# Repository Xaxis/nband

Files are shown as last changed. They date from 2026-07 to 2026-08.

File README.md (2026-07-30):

# nband

An open multi-spectral sensing platform. A buildable sensor node that watches the sky across as many as thirteen bands at once, timestamps everything against a satellite-disciplined clock, and publishes what it records.

**Site:** https://nband.space

The motivating question is whether anything crosses the sky that conventional explanations do not cover. The design commitment is that the instrument is never allowed to claim more than it measured. The top of the classification ladder is `unresolved`, not `artificial`, and the schema has no way to encode the latter.

## What is in here

Hardware, firmware, database, analysis, and documentation are one repository on one version, because documentation that drifts from the hardware is worse than no documentation. `make check` fails when they diverge.

```
schema/         Canonical source of truth. bands.json and spec.json define the band
                taxonomy, enums, hypothesis set, and platform thresholds. Everything
                else is generated from them.
firmware/       The node agent. Python, runs on a Raspberry Pi 5, runs anywhere in
                --simulate mode.
discriminator/  The analysis engine. Subtracts known sources, scores hypotheses,
                produces verdicts that explain themselves.
apps/web/       The site: landing, documentation, hardware registry, live telemetry,
                and the grid ingest API.
content/        Flat-file documentation, versioned beside the firmware it describes.
tools/          codegen, the four checks, seeding, fixtures, palette derivation.
```

## The parts that are load-bearing

**One schema, three languages.** `tools/codegen.mjs` generates TypeScript for the website and Python for the firmware from `schema/*.json`. The Postgres enums are checked against the same files. Adding a band means editing one file; there is no second place to forget.

**Timing is the whole product.** A node disciplines its clock against GNSS with a hardware pulse-per-second signal and holds a few hundred nanoseconds. That is what makes cross-band coincidence a measurement rather than a figure of speech, and what lets two nodes triangulate a real altitude. A node without PPS keeps recording and marks its data as unable to contribute geometry.

**Nanoseconds travel as strings.** Nanoseconds since the epoch is roughly 1.8×10¹⁸, two orders of magnitude past `Number.MAX_SAFE_INTEGER`. Sent as a JSON number it arrives already rounded, destroying exactly the precision the PPS lock exists to buy. Nodes send decimal strings; the API parses them as `BigInt`.

**Unavailable is not the same as clean.** Every catalogue lookup is recorded in three states: matched, checked and clean, or unreachable. An event with any unreachable catalogue cannot be called unresolved. Conflating those two is the easiest way to manufacture a mystery, and the test suite exists mostly to prevent it.

**Colour never carries meaning alone.** Fourteen bands cannot be separated by hue under colour-vision deficiency at any spacing; this was measured with a palette validator, not assumed. So band colour is an accent beside a written label, and the telemetry view uses one chart per band rather than fourteen overlaid traces.

**Requests are single-use.** Every write is Ed25519-signed over the path, a timestamp, and a nonce as well as the body. The grid records each nonce, so a captured request cannot be replayed to fabricate archive content.

## Running it

Everything goes through `make`. `make` on its own lists the targets.

```bash
make install        # JS and Python dependencies
make dev            # site at localhost:3000, against the mock feed
make check          # everything CI runs
make node-selftest  # open every channel in simulation, no hardware needed
```

`make check` runs seven things, each of which is a claim this repository makes
about itself:

| Target | What it proves |
|---|---|
| `make drift` | Generated bindings, Postgres enums, document versions, part cross-references, tier budgets, power sizing, band counts and the documented wire protocol all agree |
| `make parity` | The browser discriminator scores identically to the Python engine |
| `make links` | Every internal link resolves and every document has a route |
| `make privacy` | A published node position cannot be de-fuzzed back to an operator's home |
| `make test-firmware` | Clock grading, bounded buffers, coincidence triggering, driver registry |
| `make test-discriminator` | The scoring engine, mostly asserting what it refuses to conclude |
| `make lint` `make build` | Types, lints, and a production build |

## Build one

Three tiers, priced from named vendor pages on a stated date. Component pricing moved sharply through 2026 as memory supply was redirected to AI datacentre demand, so the entry tier targets a 2 GB board and the firmware is written to fit it rather than pretending prices held.

See [/hardware](https://nband.space/hardware) for the bill of materials and [/build](https://nband.space/build) for the guide. Every build step ends in something you can verify before spending money on the next one.

If you are within 60 km of an existing node, put yours there. A second node with a good clock converts both from bearing-only instruments into a system that measures position, and that is worth more than any single sensor upgrade.

## Documentation

Everything is published at [nband.space](https://nband.space) and lives in
`content/` beside the firmware it describes. Start at
[nband.space/docs](https://nband.space/docs), or go straight to one of these:

- [What the fourteen bands can and cannot see](https://nband.space/bands)
- [Bill of materials, wiring, and power budget](https://nband.space/hardware)
- [Build guide](https://nband.space/build), eleven steps, each one verifiable
- [How verdicts are reached](https://nband.space/discriminator), runs live
- [Safety and regulation](https://nband.space/safety), read before building an emitter

## Contributing

See [CONTRIBUTING.md](CONTRIBUTING.md), and
[SECURITY.md](SECURITY.md) for the threat model and how to report a
vulnerability. Changes of note are recorded in [CHANGELOG.md](CHANGELOG.md).

## Licence

Code MIT. Documentation and recorded data CC BY 4.0. See [LICENSE](LICENSE).

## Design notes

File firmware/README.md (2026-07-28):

# nband node agent

The software that runs on the node. Samples every configured band, decides what is worth keeping, and delivers it to the grid without losing anything when the link goes down.

Runs on a Raspberry Pi 5. Runs on a laptop in `--simulate` mode, which is how the build guide lets you verify the whole pipeline before any hardware arrives.

```bash
python3 -m venv .venv && .venv/bin/pip install -e '.[pi]'
python3 -m nband_node.agent --config config.example.toml --simulate --self-test
```

## The memory budget

Tier 1 targets a 2 GB Raspberry Pi 5 because the 8 GB board costs USD 110 more at July 2026 prices, and that difference is a quarter of the entire tier 1 budget. Fitting in 2 GB is not an optimisation applied afterwards; it is a constraint the architecture is built around.

Three rules make it hold.

**Every buffer is bounded at construction.** `RingBuffer` takes a capacity and never resizes. Ring depth is `sample_rate_hz × (pre_roll_s + post_roll_s)`, capped at 20,000 samples per channel. A tier 2 node with eight channels holds well under 50 MB of sample history, and that figure is the same after a month of uptime as after a minute.

**Nothing decoded is queued.** Imaging drivers return a photometric scalar per frame, not the frame. A full 12-megapixel capture is roughly 36 MB decoded; queuing even a few would exhaust the board. Frames are held only inside the driver for the duration of one read, and full captures reach durable storage only when a detection promotes the window that contains them.

**The noise floor is constant-memory.** `NoiseFloor` uses Welford's algorithm rather than a window of recent samples, so a channel's adaptive threshold costs three floats regardless of how long the node has been running. A windowed implementation at 10 Hz over an hour would be 36,000 samples per channel for no additional accuracy.

The practical consequence for driver authors: if your `read()` allocates something proportional to uptime, or holds a decoded frame past return, it will work on your desk and strand a node in the field three weeks later.

## What the agent does each cycle

Reads any channel whose next sample is due. Appends the sample to that channel's ring buffer and to the local spool. Updates the channel's noise floor, but only with clean samples, because feeding a saturated reading into the floor teaches the channel that saturation is normal.

If a sample exceeds its channel's `trigger_sigma`, it is offered to the coincidence detector. A single crossing is held, not published. It becomes a detection when a second *band* crosses inside the coincidence window, or when one channel's excursion is extreme enough to be worth recording alone at a much lower score. Two cameras both seeing a bird is one observation, not corroboration, which is why the detector counts distinct bands rather than distinct channels.

When a detection fires, the window is promoted: every channel's buffered samples from `pre_roll_s` before the trigger to `post_roll_s` after it are written to the detection spool. That pre-roll is the reason the ring buffer exists at all.

## Offline-first

A node on a desert mast with intermittent backhaul is the design case, not the edge case.

Samples go to an append-only local spool first and are removed only once the grid acknowledges them. When the spool reaches its ceiling it drops the oldest *telemetry* and never touches detections: losing an hour of barometric pressure costs almost nothing, and losing a detection costs the entire point of the exercise.

A node with no network at all is a valid deployment. It accumulates until the disk fills and uploads in order when a link appears.

## Timing

The agent does not discipline the clock. `chrony` does that, against the GNSS pulse-per-second signal. What the agent does is read back how well disciplined the clock currently is and record that honestly with every sample.

`Clock.update_from_chrony` grades conservatively: the reference must actually be a PPS source and the RMS offset must be under a microsecond before the node claims `gnss_pps`. Anything else is `ntp` or `freerun`, and every sample taken under those conditions carries the clock-degraded quality bit.

This matters because cross-node time-of-arrival is the only way the grid measures position rather than bearing, and a node that overstates its timing corrupts geometry for every node it is correlated against.

## Layout

```
nband_node/
  config.py            TOML loading and hard validation
  core.py              Clock, RingBuffer, NoiseFloor, CoincidenceDetector
  sensors.py           Driver interface, simulated twins, 17 real drivers
  agent.py             Main loop, identity, spool, grid client, CLI
  schema_generated.py  Generated from schema/. Never edit.
tests/
  test_core.py         Clock grading, buffers, triggering
  test_registry.py     Every advertised driver exists and resolves
```

## Adding a driver

Subclass `Driver`, declare a band, implement `read()`. Four things are easy to get wrong and all of them are silent:

Declare capabilities honestly. `Capabilities` is how the discriminator knows whether it may score thermal morphology or only thermal presence. Overstating it corrupts analysis rather than improving it.

Return `None` rather than a fabricated value when a read fails. Several of these sensors drop frames routinely and the pipeline handles it. A zero standing in for a missing reading poisons the noise floor.

Mark compromised samples with the quality bitfield instead of dropping them. A silent gap reads as "nothing happened" when it means "we could not trust this".

Write the simulated path. `test_registry.py` requires every band to produce a sample under `--simulate`, so that someone without your hardware can still exercise the pipeline.

## Tests

```bash
python3 tests/test_core.py       # 16 cases
python3 tests/test_registry.py   #  6 cases
```

`test_registry.py` exists because thirteen drivers were once advertised in the hardware registry and the shipped example config with no implementation behind them. That config is what the build guide tells people to run, so it would have failed at the exact moment a builder had just soldered something and had every reason to blame their own wiring.

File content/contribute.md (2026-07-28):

---
title: Contributing
description: How to add hardware variants, drivers, catalogues, and documentation without breaking the archive for everyone else.
version: 0.1.0
section: Participate
order: 70
updated: 2026-07-27
audience: Anyone who wants to extend the platform
---

nband is built on the assumption that people will construct it with parts nobody anticipated. The registry, the driver interface, and the capability declaration all exist to make that a supported path rather than a fork.

## The one rule that matters

Do not add anything that makes the archive claim more than the instrument measured.

Almost every design decision in this project follows from that. It is why the discriminator records a catalogue it could not reach separately from a catalogue that found nothing, why range stays null unless something measured it, why a driver declares what it cannot resolve, and why the top of the classification ladder is "unresolved" rather than anything more interesting. A contribution that quietly widens what the data appears to support will be refused even if the code is good.

## Registering a hardware variant

If you built a node with a substitute part, register it. An unregistered part means the grid receives data it cannot calibrate and has to discount.

A variant entry needs the band it serves, the driver it uses, a sourced price with a date, and an honest account of what it cannot do. The MLX90640 entry is the model to follow: it is a fully supported thermal variant at a fifth of the reference price, and its registry entry states plainly that at 768 pixels it can establish thermal presence but not thermal morphology. The discriminator reads that and scores accordingly.

New variants enter as `submitted`. Data from a submitted part is accepted and flagged. Running the conformance suite and having it pass moves the part to `verified`, at which point the flag comes off. Parts that do not work are documented as `unsupported` rather than deleted, so nobody buys one twice.

## Writing a driver

Subclass `Driver`, declare a band, implement `read()`, and return a `Sample`. The parts that are easy to get wrong:

Declare your capabilities honestly. `Capabilities` is how the discriminator knows whether it may score thermal morphology or only thermal presence. Overstating it corrupts analysis rather than improving it.

Return `None` rather than a fabricated value when a read fails. A dropped frame is normal for several of these sensors and the pipeline handles it. A zero standing in for a missing reading is a lie that propagates into the noise floor.

Mark compromised samples instead of dropping them. The quality bitfield exists so that a saturated sensor, a stale calibration, or a shutter event stays visible in the record. A silent gap reads as "nothing happened" when it means "we could not trust this".

Write a simulated path. Every driver needs to work under `--simulate` so that someone without your hardware can still exercise the pipeline, and so the build guide's verification steps work before parts arrive.

## Adding a catalogue

Catalogues subtract known sources. A new one implements `check()` and returns a `CatalogResult`.

The critical contract is that unreachable is not the same as clean. If your provider times out, raises, or returns nothing, return `available=False`. Returning a no-match result for a failed lookup is the single most damaging bug possible in this codebase: it manufactures mysteries by making unchecked events look checked. The test suite has cases for exactly this and they are not optional.

## Changing the schema

`schema/bands.json` and `schema/spec.json` are the source of truth for the whole platform. Editing them and running `yarn codegen` regenerates the TypeScript and Python bindings; `yarn check:drift` fails if you forgot.

Band `ordinal` values are persisted in the database. Reordering bands is a breaking change and needs a schema version bump and a migration, not an edit.

## Documentation

Content lives in `/content` at the repository root, next to the firmware rather than inside the website. Each document declares the platform version it was written against, and the drift check fails the build when a document claims a version that no longer exists.

If you change firmware behaviour that a document describes, change the document in the same commit. Documentation that drifts from the hardware is worse than no documentation, because it is trusted.

## Running the tests

Everything goes through `make`, and `make check` is exactly what CI runs. Run that before opening a pull request and there should be no surprises:

```bash
make install     # JS and Python dependencies, pinned to match CI
make check       # everything CI runs
```

If you want the fast loop while working, `make check-fast` skips the production build. Each target is a claim the repository makes about itself:

| Target | What it proves |
|---|---|
| `make drift` | Generated bindings, Postgres enums, document versions, part cross-references, tier budgets, power sizing, band counts and the documented wire protocol all agree |
| `make parity` | The browser discriminator scores identically to the Python engine |
| `make links` | Every internal link resolves and every document has a route |
| `make privacy` | Published node positions cannot be de-fuzzed back to an operator's home |
| `make test` | Clock grading, bounded buffers, coincidence triggering, driver registry, and the scoring engine |
| `make lint` `make build` | Types, lints, and a production build |

The discriminator tests are mostly about refusal: they assert that events get downgraded when the clock is degraded, when a catalogue was unavailable, or when only one band saw it. Those are the cases that protect the archive from false claims, which is the only failure mode that actually costs this project anything.

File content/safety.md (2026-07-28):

---
title: Safety and regulation
description: Optical, radio, electrical, and radiological hazards in an nband build, and the rules that apply to each.
version: 0.1.0
section: Reference
order: 60
updated: 2026-07-27
audience: Anyone building the active-emission module, and everyone else before they power up outdoors
---

Most of a nband node is passive and carries no more risk than a garden camera. The exceptions are concentrated in the optional active-emission module and in the fact that the whole thing lives outdoors on a mast.

Nothing here is legal advice. Rules differ by country and the operator is responsible for the ones that apply where the node stands.

## The passive build is genuinely low risk

Tier 1 emits nothing at all. Tier 2 is not passive: its bill of materials includes a 24 GHz tracking radar, which is an intentional radiator, and the optional 850 nm beacon if you fit one. Everything else in both tiers only receives. The hazards are otherwise the ordinary ones of outdoor electronics: a lithium battery that should not be punctured or charged below freezing, a mast that should not be raised near overhead lines, and mains wiring that should be on a residual-current device if it exists at all.

The one non-obvious risk is the lens. A large-aperture lens pointed at the sky will, at some point, be pointed near the Sun. This will not hurt you but it can destroy a sensor in seconds and can ignite debris inside an enclosure. If your node tracks, add a solar-exclusion zone to its pointing limits. If it stares, accept that a fixed camera looking upward will image the Sun daily and choose an aperture accordingly.

## Ultraviolet and infrared sensors are receivers, not emitters

The UV and thermal channels detect radiation, they do not produce it. There is no exposure risk from the sensors themselves. The germanium window in front of a thermal camera is brittle and moderately expensive and is the part most likely to be damaged by cleaning it with the wrong cloth.

## The infrared beacon is the one optical emitter

The 850 nm pulsed beacon is an LED rather than a laser. That matters for which standard applies, not for whether it is safe: LEDs are assessed under IEC 62471 photobiological safety rather than the IEC 60825 laser classes, and a 5 W peak infrared emitter is not automatically in the exempt group at close range. Earlier wording here implied the LED construction alone put it below a Class 3R threshold, which conflates two different standards.

Treat it as a real emitter. 850 nm is barely visible, so the blink reflex does not protect you. Do not look into it at close range, do not view it through binoculars or a camera with gain, keep it above head height, and do not point it at a road, a footpath, or anything on approach to an airfield.

Point it above the horizon. The node knows its own emission schedule exactly, so any near-infrared return correlating with the code is recognised as self-illumination and subtracted rather than reported.

## The broadband RF source is not something you can build under Part 15

An earlier revision of this page said the optional noise source ran "under 100 mW effective radiated power, inside FCC Part 15". That was wrong in a way worth stating plainly, because someone might have built it.

There is no general 100 mW allowance in Part 15. The 1 W figure people remember applies to digitally modulated or frequency-hopping systems inside the ISM bands under §15.247, and 400 to 600 MHz is not an ISM band. An intentional radiator there falls under the general radiated-emission limits of §15.209, which are expressed as field strength at three metres and correspond to something on the order of nanowatts, not milliwatts. Spreading the signal does not help: §15.209 constrains field strength, not power spectral density.

So that emitter has been withdrawn from the reference design. Building a deliberate broadband radiator in that range at any useful power requires an amateur or experimental licence, and if you hold one you already know more about the conditions attached to it than this page can usefully tell you.

The millimetre-wave radar modules are a different case. They are certified devices sold for exactly this use and operating in bands allocated for it. Leave their firmware alone; the certification belongs to the module as shipped, not to whatever you reflash it with.

## The radioisotope module needs to be read carefully

The optional signature module aggregates the encapsulated americium-241 foils already present in domestic ionisation smoke detectors. Roughly ten of them, at about 0.9 microcuries each, sit behind a 2 mm aluminium heat sink and an acrylic housing. The aluminium and acrylic absorb the alpha and beta emission entirely while remaining largely transparent to the 59.5 keV gamma line, which is the signature the module exists to produce.

This page published the dose figure wrong twice, in opposite directions. Both are corrected here rather than quietly replaced, because both were live long enough to be read.

The figure first published was roughly 40 nanogray per hour at one metre, described as "well under one percent of natural background". A later revision retracted it and claimed about 1,070 nanosieverts per hour, three times background. **The retraction was itself wrong**, by about a factor of a hundred, and it is the number that stood.

The error was a dropped exponent. The tabulated air-kerma rate constant for americium-241 is roughly 3.2 × 10⁻² mGy·m²/(GBq·h). Converting milligray to microgray multiplies by a thousand and converting gigabecquerels to megabecquerels divides by a thousand, so those cancel and the value in the units wanted is still 3.2 × 10⁻², or 0.032 µSv·m²/(MBq·h). It was published as 3.2.

Worked through properly: nine microcuries is 0.33 megabecquerels. The 59.5 keV line alone, at 35.9 percent yield against NIST mass energy-absorption coefficients for air, gives about **1 nSv/h at one metre**. Including the neptunium L X-rays around 14 to 21 keV, which are soft but numerous, raises it to about **9 nSv/h**. The most conservative published constant found in a supplier safety sheet, 85 µSv/h per GBq, gives **28 nSv/h**. Natural background averages around 340 nSv/h.

Across the full spread of defensible values the answer is between a fraction of a percent and about eight percent of background. It is never above background. The figure this page published as three times background was wrong in the alarming direction by roughly two orders of magnitude, and the original 40 nGy/h was about right in magnitude, though its label was not: 40 nGy/h is around twelve percent of background, not "well under one percent".

Shielding was also described wrongly. Two millimetres of aluminium passes about 86 percent of the 59.5 keV line, which is where the claim that it "does not rescue it" came from, but only about 16 percent of the 17 keV L X-rays, and those dominate the bare dose. The housing removes most of it. That was never the reason to shield: alpha and beta are what the aluminium and acrylic stop, and they do that completely.

**The dose was never the problem.** A few percent of background at one metre, falling off as the square of distance, is not what should stop you. The regulatory position is.

The regulatory position was published wrongly too, and it matters more than the dose figure. An earlier revision said the assembly "stays below the United States NRC general-license threshold in 10 CFR 30.15". That is not what 10 CFR 30.15 says. It is an exemption rather than a general license, general licenses live in Part 31, and §30.15(a)(7) exempts "ionization chamber smoke detectors containing not more than 1 microcurie of americium-241 per detector in the form of a foil and designed to protect life and property from fires". The limit is per detector, the exemption attaches to the detector as a fire-protection device, and there is no aggregate activity allowance to sit beneath.

Ten foils removed from their detectors and epoxied into an aluminium and acrylic cartridge is therefore outside that exemption on every count: nine times the per-item activity, no longer in a device designed to protect life and property from fires, and no longer the article the exemption describes. §30.15(b) points anyone wanting to incorporate byproduct material into a product towards a specific license under §32.14.

nband does not assert that building this is lawful, and the previous wording implied a regulatory cover that does not exist. The aggregated cartridge has been removed from the reference bill of materials. If you intend to pursue a gamma lure seriously, do it under a specific license with your regulator's knowledge, not on the strength of a citation you read on a website.

The handling advice stands regardless: do not open, machine, dissolve, or heat a foil. It is dangerous if the encapsulation is breached and ingested, and unremarkable if left alone.

Outside the United States, rules differ substantially and some jurisdictions prohibit possession of multiple sources regardless of individual activity. Check before building, not after.

If any of this is uncomfortable, skip the module. It is genuinely optional, every passive band works without it, and the platform is designed so that an emitter-free node is a first-class participant rather than a degraded one.

## Cameras and other people

A node pointed at the sky is not a surveillance device, but a wide-angle lens on a mast usually catches some ground. In populated areas, tilt the field of view at least 15 degrees above the horizon and confirm what is actually in frame rather than assuming.

Published node positions are fuzzed to the precision the operator declares, defaulting to one kilometre. The offset is deterministic, so repeated readings cannot be averaged back to the true point, and it is keyed on a server-held secret, so it cannot simply be recomputed and subtracted. Both properties are required; in 0.1.0 this platform had only the first, and the published position was recoverable to a few metres by anyone who read the source. That protects the operator. It does nothing for the neighbours, which is the operator's job.

## Aviation

A ground node on a mast is not an aviation matter until the mast is tall. Structures above roughly 60 metres, and anything near an aerodrome approach, are subject to marking and notification requirements almost everywhere.

If you are mounting the payload on an aircraft of any kind, everything about that is outside the scope of this guide and squarely inside your national aviation regulator's.

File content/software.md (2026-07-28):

---
title: Software and configuration
description: Flashing, configuration, calibration, the data schema, and the API surface a node speaks to the grid.
version: 0.1.0
section: Build
order: 20
updated: 2026-07-27
audience: Someone with a node running who wants to change how it behaves
---

The node agent is a single Python package with no service dependencies beyond the grid endpoint. It is designed to run for months without attention on a board with 2 GB of memory, which constrains the architecture more than anything else: every buffer is bounded at construction, nothing in the hot path grows with uptime, and decoded frames are never queued.

## The configuration file is the whole interface

A node is defined entirely by one TOML file. There is no hidden state and no auto-detection, deliberately. A node that silently reconfigures itself produces an archive nobody can interpret two years later, because the metadata explaining a reading is no longer recoverable from the reading.

The file is validated hard at startup and the agent refuses to run if anything is ambiguous. That includes rejecting a `trigger_sigma` on a context band, which is how the platform structurally prevents a barometric wobble from being reported as a detection.

```toml
[node]
name = "KP-01 Sonoran"
tier = "t2"
pre_roll_s = 15.0     # buffered history promoted when a trigger fires
post_roll_s = 15.0

[site]
latitude = 31.9403
longitude = -109.3120
elevation_m = 1402.0
location_precision_m = 1000   # published position is fuzzed by this radius

[grid]
endpoint = "https://nband.space"
node_slug = "kp-01-sonoran"
key_path = "/var/lib/nband/node.key"

[[channel]]
id = "vis.wide"
band = "vis"
part = "cam-hq-imx477"
unit = "mag/arcsec2"
sample_rate_hz = 0.2
trigger_sigma = 4.5
```

`part` refers to an entry in the hardware registry and resolves automatically to a driver. Specify `driver` directly only when using hardware the registry does not know about, and register the variant afterwards so the next person does not have to guess.

## Choosing trigger thresholds

`trigger_sigma` is measured in standard deviations of that channel's own running noise floor, not in absolute units. This is what lets the same configuration work at a rural site and a suburban one whose radio floor is thirty decibels higher.

The floor is computed with Welford's algorithm over the channel's whole history, so it adapts slowly and does not need recomputing from a window. It requires 64 samples before it will fire at all, which on a 0.2 Hz channel is five minutes. A node that has just restarted is deliberately deaf for that period rather than firing on its own startup transient.

Start at `4.5` for imaging channels and `6.0` for radio. Lower values produce more candidate events, which is not the same as producing more information: the coincidence requirement means a channel that fires constantly mostly generates noise for the other channels to fail to corroborate. If a channel is triggering more than a few times an hour, raise its sigma rather than filtering downstream.

## Calibration

Three channels need calibration before their data means anything in absolute terms.

The magnetometer needs a hard-iron offset, measured by rotating the sensor through all orientations and recording the midpoint of each axis. Without it the channel still detects changes correctly but reports the wrong absolute field, which matters when comparing across nodes.

The thermal camera's flat-field shutter runs automatically every few minutes and blanks the stream for roughly half a second. The agent marks those samples with the calibration-stale quality bit rather than dropping them, so a gap in the record is always visible as a gap rather than as an absence of events.

The sky-brightness channel needs a zero point, which is the reading on a clear moonless night with no artificial light in frame. Until you set it, the channel reports relative values and the discriminator scores it accordingly.

## The data schema

Everything the platform records derives from two files in the repository, `schema/bands.json` and `schema/spec.json`. Those define the band taxonomy, the enumerations, the hypothesis set, and the platform-wide thresholds. TypeScript for the website and Python for the firmware are generated from them by `yarn codegen`, and a drift check fails the build if the generated files are stale.

This is why the website and the node cannot disagree about what a band is. Adding a band means editing one JSON file and regenerating; there is no second place to update and forget.

Two details in the storage schema are worth knowing. Timestamps are stored as a Postgres `timestamptz`, which holds microseconds, plus a separate `t_ns_offset` column holding the remaining 0 to 999 nanoseconds. Nanosecond fidelity therefore survives the round trip, which matters only for cross-node time-of-arrival work but matters completely there. And verdicts are versioned per discriminator run rather than overwritten, so re-running an improved discriminator over the archive produces a new verdict alongside the old one instead of quietly rewriting history.

## The API surface

Four endpoints, all requiring an Ed25519 signature using the node's key. The signature covers a canonical payload, `nband/v1\n{path}\n{timestamp}\n{nonce}\n{body}`, rather than the body alone, so a captured request cannot be replayed onto a different endpoint or reused at all. See [the API reference](/reference/api) for the exact header set.

`POST /api/grid/register` enrols a node and declares its channels. Re-enrolment by a node signing with the key already on record is allowed and is how you update the channel list after adding hardware. Enrolling a new slug requires the grid enrolment secret.

`POST /api/grid/telemetry` accepts up to 5000 samples per batch. The handler provisions any monthly partitions the batch touches before inserting, so a node returning from three weeks offline backfills correctly rather than dumping into a default partition.

`POST /api/grid/detections` accepts up to 50 detections per batch and opens a single-node event for each so the discriminator has something to score.

`POST /api/grid/heartbeat` reports health and is the only thing that moves a node between online, degraded, and offline. A node whose clock has fallen below GNSS discipline is marked degraded even when every sensor is healthy, because without the pulse-per-second lock it can no longer contribute the geometry that makes it useful.

Reads need no authentication. The archive is public, and the browser-visible key is read-only by row-level-security policy rather than by convention.

## Running offline

The node buffers to a local append-only spool and removes records only once the grid acknowledges them. When the spool reaches its configured ceiling it drops the oldest telemetry first and never touches detections, because losing an hour of barometric pressure costs almost nothing and losing a detection costs the entire point of the exercise.

A node with no network at all is a valid deployment. It will accumulate data until the disk fills, and everything uploads in order when a link appears.

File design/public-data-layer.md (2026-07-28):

# The public data layer

Status: **plan, not implementation.** Nothing described here beyond the ingest
and storage section exists yet. It lives in `design/` rather than `content/`
precisely so it is not published as though it were a feature.

Written 2026-07-28, against platform v0.1.0.

## What is actually built today

Worth stating plainly, because the gap between the two halves is wide.

The write path is real. Nodes enrol with an Ed25519 key, sign every request
over a canonical payload binding path, timestamp and single-use nonce, and post
to four endpoints. Telemetry lands in monthly Postgres partitions provisioned
on demand. Detections open single-node events. Verdicts are versioned per
discriminator run rather than overwritten. Catalogue checks record
matched, checked-clean and unreachable as three distinct states. Row-level
security makes the browser key read-only, and simulated nodes are excluded from
every public read by policy rather than by convention.

The read path is not. `NEXT_PUBLIC_FEED_SOURCE` is `mock` in all three Vercel
environments, so `/grid` and `/telemetry` render synthetic data and have never
displayed a row from the database. The `supabase_realtime` publication contains
no tables, so nothing streams. There are no materialized views, so nothing is
aggregated. Site search covers documents, parts and bands, and does not reach a
single detection. There is no export.

So: the archive is designed to be indexable, searchable and aggregated. It is
none of those things yet, and the site is not even reading it.

## The order this has to happen in

Realtime before archive, and archive before export. Each depends on the one
before it having a settled shape, and building the query surface against mock
data would mean designing against a fiction.

### 1. Read the real database — gated on data existing

**This does not happen until nodes are actually reporting.** An empty real feed
renders as a broken page, and a mock that is honestly labelled communicates
more than a live view of nothing. The switch is gated on data, not on the code
being ready.

Replace the mock feed with the Supabase one behind the existing `feed`
interface, which was written for exactly this substitution. Two things must be
true before the switch: the empty state has to read as "no node has reported
yet" rather than as a broken page, and the page has to say which source it is
showing. A site that silently swaps synthetic data for real data has taught its
readers that the distinction does not matter.

Keep the mock feed. It is how the interface is developed without a node, and
how the empty and degraded states stay testable.

### 2. Realtime

Two different needs, and conflating them produces something that serves
neither.

**Live telemetry** is high-rate, low-value-per-row, and only interesting in the
last few minutes. A node at 20 Hz across ten channels is 200 rows a second, and
a browser does not want them individually. This wants a server-side aggregate
pushed at a fixed cadence — one message per node per second carrying a summary
per channel — not a row-level subscription.

**Detections and verdicts** are the opposite: rare, individually meaningful,
and worth interrupting for. These want a genuine row-level subscription.

```
publication supabase_realtime:  detections, events, verdicts, node_heartbeats
                                (never telemetry — see above)
```

The subscription must respect the same RLS the REST surface does, so a
simulated node's detections never appear. That is worth an explicit test rather
than an assumption, because it is exactly the leak that migration 0005 already
had to close once.

Backpressure is a client concern the plan has to name: a tab left open for a
day must not accumulate unbounded state. Bounded ring buffer, drop oldest,
display the drop count. Silent loss is the failure mode this project exists to
avoid, and that applies to the viewer as much as to the node.

### 3. The archive

The query surface people will actually want:

```
GET /api/archive/events
  ?from=<iso8601>&to=<iso8601>
  &band=<band id, repeatable>
  &classification=<enum, repeatable>
  &node=<slug, repeatable>
  &min_score=<0-100>
  &corroboration=<enum>
  &catalogues=complete|any        # complete excludes any unreachable check
  &cursor=<opaque>&limit=<=200
```

`catalogues=complete` is the one filter that is not obvious and is the most
important. An event whose ADS-B check could not be performed is not evidence of
anything, and the default view of the archive must not mix those in with events
that were properly checked. It defaults to `complete`.

Cursor pagination, not offset: the archive only grows, and offset pagination
over a growing table silently repeats and skips rows.

Aggregation wants materialized views refreshed on a schedule, not computed per
request:

- `mv_events_daily` — count by day, band, classification, node
- `mv_node_uptime` — heartbeat coverage and clock quality distribution per node
- `mv_catalogue_availability` — how often each catalogue was reachable

That last one is a health metric for the archive itself. A rising unreachable
rate means the archive is accumulating events that could not be checked, and
that should be visible on the site rather than discovered later.

### 4. Export and citation

An archive nobody can download is not an archive. Versioned snapshots, content
addressed, with a stable schema and a documented deprecation policy:

```
/exports/2026-08/events.parquet        + .sha256
/exports/2026-08/verdicts.parquet
/exports/2026-08/MANIFEST.json         schema version, row counts, generated at
```

Every snapshot gets a citable identifier so a published analysis can name the
exact bytes it was computed from, and so a later reader can tell whether a
verdict has since been superseded. The discriminator is versioned per run for
this reason already; the export has to carry that through.

## The constraint that governs all of it

Never let the archive claim more than the instrument measured. For the data
layer specifically:

- An event with any unreachable catalogue is excluded from the default view and
  labelled wherever it does appear.
- Aggregates state their denominator. "Six unresolved events" without "of 4,200
  checked" is a number designed to mislead.
- A gap in a chart means no data, and must be visually distinct from a measured
  zero.
- Simulated data is never in a public aggregate, and the exclusion is enforced
  by policy and tested, not left to a query author to remember.
- Export snapshots are immutable. A verdict that changes produces a new row in a
  new snapshot; it never rewrites an old one.

## What has to be decided before building

- Retention. Full-rate telemetry is roughly 500 MB per node-year. Keep raw for
  90 days and downsample after, or keep everything and pay for it?
- Whether the archive API is a thin layer over PostgREST or its own route. The
  filters above, particularly `catalogues=complete`, argue for its own route.
- Rate limiting on a public read API that anyone can scrape.
- Whether verdict supersession is exposed in the API or only in exports.

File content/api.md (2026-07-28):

---
title: API reference
description: The four signed endpoints a node speaks to the grid, and the public read surface.
version: 0.1.0
section: Reference
order: 40
updated: 2026-07-27
audience: Anyone writing a client or debugging a node that will not report
---

Base URL is `https://nband.space`. Writes require a signature. Reads do not require anything.

## Authentication

Every write is signed with the node's Ed25519 private key, which is generated on the node at first run and never leaves it. Six headers accompany each request:

```
X-Nband-Node:       your-node-slug
X-Nband-Key:        base64url public key, no padding
X-Nband-Signature:  base64url signature over the canonical payload below
X-Nband-Timestamp:  seconds since the epoch, as a decimal string
X-Nband-Nonce:      a value never used before by this node
X-Nband-Schema:     0.1.0
```

The signature does **not** cover the body alone. It covers a canonical payload that binds the request to one endpoint, one moment, and one use:

```
nband/v1\n{path}\n{timestamp}\n{nonce}\n{body}
```

`{path}` is the request path exactly as sent, such as `/api/grid/telemetry`. The four newlines are literal. A signature over the body alone was valid forever, on any endpoint, and could be replayed to fabricate archive content, the three bound fields close that, and each closes a different hole. The path stops a telemetry signature being presented to `/detections`. The timestamp bounds how long a captured request stays usable: more than **300 seconds** of skew in either direction is refused with a 401. The nonce is recorded in a server-side ledger and makes the request usable exactly once inside that window; a repeat is refused with a 409.

Omitting `X-Nband-Timestamp` or `X-Nband-Nonce` is a 401, not a warning. Nodes on the body-only scheme cannot write to the grid.

The body portion is the raw bytes, so serialise once and sign the bytes you actually send. Re-serialising between signing and sending is the most common cause of a 401 that looks inexplicable.

The schema header is checked against the grid's own version. A node running a different schema is writing rows whose meaning may differ, so it is rejected with a 409 naming both versions rather than accepted and quietly reconciled.

Failures return a JSON body with an `error` string and usually a `detail` object. The node agent surfaces both; a client that discards them leaves its operator staring at a bare status code.

## POST /api/grid/register

Enrols a node and declares its channels. This is the only write that cannot use normal authentication, because the node is not on record yet. It instead proves two things: possession of the private key matching the public key it claims, by signing the request, and knowledge of the grid enrolment secret.

Re-enrolment by a node signing with the key already on record is allowed and is how you update the channel list after adding hardware. Enrolling a new slug requires the secret. The channel set is replaced wholesale, because a stale channel row would advertise a band the node no longer has, which the discriminator would read as "looked and saw nothing".

```json
{
  "slug": "kp-01-sonoran",
  "display_name": "KP-01 Sonoran",
  "tier": "t2",
  "pubkey": "<base64url>",
  "enrollment_secret": "...",
  "site": { "lat": 31.9403, "lon": -109.312, "elevation_m": 1402,
            "location_precision_m": 1000, "horizon_mask": { "0": 4.0, "180": 12.0 } },
  "channels": [
    { "channel_id": "vis.wide", "band": "vis", "unit": "mag/arcsec2",
      "sample_rate_hz": 0.2, "part_id": "cam-hq-imx477", "role": "detection" }
  ]
}
```

The response returns the `published_position`, which is your declared position offset by the precision you asked for. Check it before continuing. Your exact coordinates are not stored anywhere.

## POST /api/grid/telemetry

Up to 5000 samples per batch.

```json
{ "samples": [
  { "channel_id": "lwir.main", "band": "lwir", "t_ns": "1785177283687169000", "v": 243.12, "q": 0 }
] }
```

`t_ns` is a decimal **string**. Sent as a JSON number it exceeds what a JavaScript parser can represent exactly and arrives already rounded, which destroys the nanosecond precision the pulse-per-second lock exists to provide. A number is still accepted below the safe-integer ceiling, for hand-written requests, and rejected with an explanation above it.

The handler provisions any monthly partitions the batch touches before inserting, so a node returning from three weeks offline backfills correctly. If a partition cannot be created the request fails with a 500 rather than letting rows fall into the default partition, which is a fault that stays invisible until someone inspects the database directly.

## POST /api/grid/detections

Up to 50 per batch. Each detection also opens a single-node event so the discriminator has something to score; cross-node fusion merges events afterwards.

Omit `range_m` unless something measured it. Do not compute it from an assumed altitude.

## POST /api/grid/heartbeat

Health, every 60 seconds. This is the only thing that moves a node between `online`, `degraded`, and `offline`.

A node whose clock has fallen below GNSS discipline is marked `degraded` even when every sensor is healthy, because without pulse-per-second lock it can no longer contribute the geometry that makes a node worth having in an array.

## GET /api/archive/events

The query surface over the archive. No authentication: everything the platform records is public.

```
GET /api/archive/events
  ?from=<iso8601>&to=<iso8601>
  &band=<band id, repeatable>
  &classification=<enum, repeatable>
  &corroboration=<enum>
  &min_score=<0-100>
  &catalogues=complete|any
  &cursor=<iso8601 from next_cursor>&limit=<=200
```

`catalogues` defaults to **complete**, and this is the one parameter worth understanding before you use the endpoint. An event whose ADS-B check could not be performed is not evidence of anything: if the transponder feed was unreachable, every aircraft that night looks unexplained. Those events are excluded from the default view and asking for them with `catalogues=any` is a deliberate choice that comes back labelled in the response.

Every response carries the filters that produced it and the denominator behind it:

```json
{
  "query":  { "band": ["rf", "vis"], "min_score": 70, "catalogues": "complete", "...": "..." },
  "counts": { "returned": 12, "examined": 47, "excluded_incomplete_catalogues": 35 },
  "note":   "Events with any unreachable catalogue check are excluded...",
  "next_cursor": "2026-07-14T22:19:03.221Z",
  "events": []
}
```

`counts.examined` is there so that "twelve unresolved events" is never quoted without "of forty-seven examined". A count without its denominator is a number designed to mislead, and this endpoint is what people will build that sentence from.

Positions come back as `fix_lat`, `fix_lon` and `fix_altitude_m` with `fix_error_m` beside them, because a fix is something that was solved rather than a property the event has, and a coordinate published without its error bar is the same overclaim as a range that was assumed rather than measured. All three are null unless geometry was actually solvable.

Pagination is by cursor rather than offset. The archive only grows, and an offset into a growing table silently repeats and skips rows as it does. Pass the `next_cursor` you were given; a null means you have reached the end.

Reads are served through the same anonymous key the browser uses, so row-level security applies identically. Simulated nodes are excluded by policy rather than by the query remembering to.

## GET /api/archive/export

Bulk download, as newline-delimited JSON. An archive nobody can download is not an archive.

```
GET /api/archive/export?table=events|verdicts|detections|catalog_checks
  &from=<iso8601>&to=<iso8601>&max=<=100000
```

NDJSON rather than CSV or Parquet, for reasons that are specific rather than taste. CSV cannot represent the shape of this data: `bands` is an array, `peak_metrics` and `track` are JSON, and flattening them loses the structure that makes them worth keeping. Parquet would be better for anything columnar but needs a writer holding the result in memory, and this streams, because the archive grows without bound. NDJSON streams, survives being cut in half, and every language reads it.

The last line of every export is a manifest rather than a row:

```json
{"nband_manifest": true, "schema_version": "0.1.0", "table": "events", "rows": 5,
 "truncated": false, "sha256": "8efeda08...", "generated_at": "2026-07-28T19:24:11Z",
 "excludes": "Simulated nodes, by row-level security..."}
```

It is last because the digest is only knowable once the rows are written; a reader who wants it first can read the file backwards, and a reader who wants to stream does not have to wait. The digest covers the row lines exactly as transmitted, so an analysis can name the bytes it was computed from and a later reader can check they have the same ones. It is verifiable with `sha256sum` over everything except the final line.

`truncated` tells you whether `max` cut the result short, so a partial export is never mistaken for a complete one.

Exports go through the same anonymous key and the same row-level security as everything else, so simulated nodes are absent, and the manifest says so rather than leaving you to wonder why the row count is lower than the grid page suggests. Superseded verdicts are present and marked `is_current: false`; nothing is ever rewritten in place.

## Reading

`GET /api/telemetry?node=<slug>&from=<ms>&to=<ms>` returns band-by-band series and the events overlapping that window, capped at 31 days. It reports which feed served it, so a client can tell synthetic data from real.

Everything else is reachable through Supabase's PostgREST surface using the public anon key, which is read-only by row-level-security policy. The tables are documented under the data schema.

One exception is worth knowing before it surprises you. `select=*` against `nodes` returns a 403, and you must name the columns you want:

```
GET /rest/v1/nodes?select=slug,display_name,tier,status,lat,lon
```

The anonymous role holds column-level grants on that table rather than a table-level one, so that `pubkey` can be withheld. A node's public key is how it authenticates, it was never needed by any reader, and while it was readable it could be used to reconstruct the offset that obscures an operator's position. Every other column is public and every other table accepts `select=*` normally. New columns added to `nodes` are private until explicitly published, which is deliberate: the failure mode is a visible 403 rather than a silent disclosure.

## Rate limits and etiquette

There are no hard limits yet. The batch ceilings above are the practical ones. A node uploading every 30 seconds with a few thousand samples per batch is the design case.

If you are backfilling weeks of data after an outage, the node agent already paces itself: it drains the spool in bounded batches and stops when the grid stops accepting them, then resumes. Do not replace that with a tight loop.

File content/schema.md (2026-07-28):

---
title: Data schema
description: The contract every node, the database, the discriminator, and the website share. What each table means and why it is shaped that way.
version: 0.1.0
section: Reference
order: 30
updated: 2026-07-27
audience: Anyone reading the archive or writing against it
---

Two files in the repository define the platform: `schema/bands.json` and `schema/spec.json`. The band taxonomy, every enumeration, the hypothesis set, and the platform-wide thresholds live there and nowhere else. TypeScript for the website and Python for the firmware are generated from them, the Postgres enumerations are checked against them, and `yarn check:drift` fails the build if any of those three drift apart.

That is the whole reason the website and a node on a mast cannot disagree about what a band is. Adding one means editing a single file and regenerating.

## Bands are physics, not products

A band is defined by what it physically responds to, never by which part you bought. Two builders using different thermal cameras contribute to the same `lwir` band; the difference between them is carried by the sensor's declared capabilities rather than by pretending the data is identical.

Fourteen bands are ordered by increasing wavelength, and that order is persisted: `ordinal` is stored in the database, so reordering bands is a breaking change requiring a migration rather than an edit. Twelve are detection bands. Two are context bands that describe the conditions a detection was made under and can never produce one themselves. Thirteen of the fourteen have a sensor in the hardware registry; the gravimetric band has none and is documented as aspirational.

## Timestamps carry their own precision

A Postgres `timestamptz` holds microseconds. A GNSS-disciplined node holds nanoseconds. Rather than throwing away the difference, `telemetry` stores `t` as a `timestamptz` plus `t_ns_offset`, a small integer holding the remaining 0 to 999 nanoseconds. Full fidelity survives the round trip.

This matters in exactly one place and matters completely there: time-of-arrival differences between nodes. Everything else reads `t` alone and ignores the offset.

Nodes transmit these as decimal strings rather than JSON numbers. Nanoseconds since the epoch is roughly 1.8 × 10^18, about two hundred times larger than the biggest integer a JavaScript number can hold exactly, so a JSON number would arrive already rounded and the precision would be gone before anything could validate it. The ingest API parses them as arbitrary-precision integers.

## Every sample carries a quality bitfield

`telemetry.q` is a bitfield, not a boolean. Bit 0 means the clock was degraded when the sample was taken, bit 1 that the sensor was saturated, bit 2 that its calibration was stale, bit 3 that the node's own emitter was active, bit 4 that the value was interpolated.

Compromised samples are recorded and flagged rather than dropped. A gap in a chart reads as "nothing happened" when the truth is "we could not trust this", and those are different claims.

## Detections are local, events are global

A `detection` is one node deciding a window of data was worth keeping. It carries the bands that witnessed it, the trigger reason, the clock quality at that moment, and a bearing. Its `range_m` is null unless something physically measured it, and the schema keeps it null rather than inferring it, because an assumed range silently becomes an assumed size and an assumed speed.

An `event` is one or more detections fused into a single object, possibly across nodes. Geometry fields are populated only when geometry was actually solvable: two or more nodes with pulse-per-second lock inside the baseline limit.

## Verdicts are versioned, never overwritten

Each `verdict` records the discriminator version and schema version that produced it, and only one per event is `is_current`. Re-running an improved discriminator over the archive inserts a new verdict beside the old one and demotes the previous. An event called unresolved in 2026 and explained in 2028 keeps both entries, and the history of how the platform's opinion changed is itself part of the record.

## Catalogue checks record what was not checked

`catalog_checks` has an `available` column separate from `matched`. Three outcomes are distinguishable: a catalogue matched the event, a catalogue was reachable and found nothing, or a catalogue could not be consulted at all.

This is the most important design decision in the schema. If the aircraft transponder feed was down, every aircraft that night looks unexplained, and a system that records only "no match" will confidently manufacture mysteries out of its own outages. An event with any unavailable catalogue is structurally barred from the top of the classification ladder.

## Node positions are deliberately imprecise

Operators run these at home, so an exact coordinate is a home address. `nodes.lat` and `nodes.lon` are already fuzzed when written; the true position is never stored anywhere. `location_precision_m` records how much fuzz was applied so downstream geometry can widen its error bars rather than treating a fuzzed point as exact.

The offset has to be two things at once, and both are required.

It must be **deterministic** per node, because an offset regenerated on each request is averaged away by anyone patient enough to collect samples, and the mean of that collection is the operator's front door.

It must also be **unguessable**, because a deterministic offset a stranger can recompute is not an offset at all. It is the true position written in a cipher whose key is printed beside it.

So the bearing is an HMAC keyed on a salt held only in the server's environment, and the distance is drawn as `precision × √u` so the true point is uniform across the whole disc rather than pinned to its rim. A searcher holding the slug, the declared precision, the published coordinate and every line of this codebase is left with the full disc: for the default one-kilometre precision, about three square kilometres, with a median error near 700 m. `tools/check-privacy.mjs` measures that distribution on every build rather than taking this paragraph's word for it.

`horizon_mask` maps azimuth to the minimum elevation at which sky is actually visible. Without it, "nothing detected to the north" is ambiguous between a clear sky and a ridgeline, and the archive cannot tell you which.

## Reading it

Everything is public. The browser-visible key is read-only by row-level-security policy rather than by convention, and every write goes through the signed ingest API using the service role.

```sql
-- Unresolved events with their reasoning, most recent first.
select e.t_start, e.bands, v.anomaly_score, v.explanation
  from nband.events e
  join nband.verdicts v on v.event_id = e.id and v.is_current
 where v.classification = 'anomalous_unresolved'
 order by e.t_start desc;

-- Which catalogues were unavailable, and how often. A high count here means
-- the archive is accumulating events that could not be properly checked.
select source, count(*) filter (where not available) as unavailable, count(*) as total
  from nband.catalog_checks
 group by source order by unavailable desc;
```

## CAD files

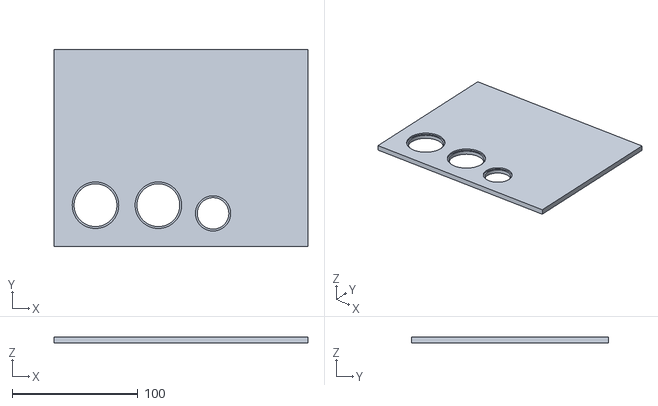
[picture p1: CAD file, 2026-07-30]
apps/web/public/boards/case-printed-asa-lid.stl
202.0 x 157.0 x 5.00

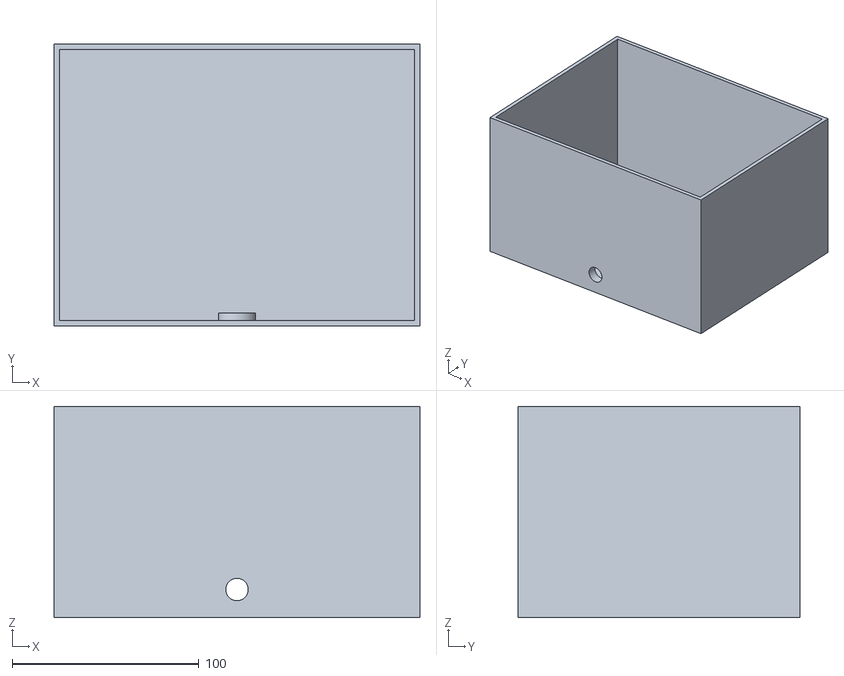
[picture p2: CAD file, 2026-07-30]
apps/web/public/boards/case-printed-asa-body.stl
196.0 x 151.0 x 113.0

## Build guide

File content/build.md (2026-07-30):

---
title: Build guide
description: Eleven steps from a bare board to a node reporting to the grid. Every step ends in something you can check before you spend money on the next one.
version: 0.1.0
section: Build
order: 10
updated: 2026-07-30
audience: Someone mid-build with a soldering iron down
---

Every step below ends in a verification: a command that prints an expected value, a file you can open, a number you can compare. If a step does not verify, stop there. The failure modes listed under each one cover most of what actually goes wrong, and continuing past a failed step means debugging two problems at once later.

The order is deliberate. Timing comes before sensors, one working sensor comes before five, and the box comes before the site, because a sensor that fails once the lid is on fails quietly and you want to find that indoors. You can stop after step 5 and have a node that contributes usefully to the grid.

## Before you start

You need a Raspberry Pi 5 (2 GB is enough and saves USD 110 over the 8 GB board at July 2026 prices), an endurance-rated microSD card, a 27 W USB-C supply, and the GNSS receiver. All four are in the bill of materials with sourced prices. Everything else can arrive later.

Two of those are worth a sentence each, because the obvious choice is wrong in both cases. Buy the card for write endurance rather than for speed class: a node writes its spool continuously for years and never launches an application, so the A2 random-read rating that sells consumer cards buys nothing here, and a card that wears out takes with it the only copy of anything the grid has not yet acknowledged. Buy the supply for its Power Delivery profile: the Pi 5 asks for 5 A over USB-C and quietly settles for 3 A on a supply that cannot offer it, which caps everything downstream of the USB ports at 600 mA. A node that runs for weeks and then starts dropping a channel under load is usually a node on a phone charger.

Two things are worth knowing now. The node runs headless, so you will need either SSH or a serial console. And the single most common way this build fails is skipping the pulse-per-second wiring in step 3, because it is fiddly and nothing appears broken without it. A node without PPS can never contribute to multi-node geometry, which is most of what the grid is for.

## Step 1: Flash and boot

Write Raspberry Pi OS Lite (64-bit) to the card. Use the Imager's advanced options to set the hostname, enable SSH, and configure your network before first boot; doing it afterwards on a headless machine is harder than it needs to be.

Boot, then update and install the packages the node needs:

```bash
sudo apt update && sudo apt full-upgrade -y
sudo apt install -y git python3-pip python3-venv chrony pps-tools i2c-tools gpsd
```

**Verify.** You are on the expected kernel and the board reports 2 GB or more:

```bash
uname -m && free -h | awk '/Mem:/ {print $2}'
```

Expected: `aarch64` and a memory figure at or above `1.9Gi`. If `uname -m` prints `armv7l` you flashed the 32-bit image; reflash. The node agent requires 64-bit.

## Step 2: Enable the buses

The sensors sit on I2C, SPI, and the serial port. Enable them and free the UART from the login console, which claims it by default:

```bash
sudo raspi-config nonint do_i2c 0
sudo raspi-config nonint do_spi 0
sudo raspi-config nonint do_serial_hw 0
sudo raspi-config nonint do_serial_cons 1
sudo reboot
```

**Verify.** After the reboot, the buses exist:

```bash
ls /dev/i2c-* /dev/spidev* /dev/ttyAMA*
```

Expected: at least `/dev/i2c-1`, `/dev/spidev0.0`, and `/dev/ttyAMA0`. If `/dev/ttyAMA0` is missing, `do_serial_cons` did not take; check that `console=serial0` is gone from `/boot/firmware/cmdline.txt`.

## Step 3: Wire and verify the pulse-per-second signal

This is the step that determines whether your node is a member of an array or a lone camera. Do not skip it.

Wire the GNSS receiver: `VCC` to 3.3 V, `GND` to ground, `TX` to the Pi's `RX` (GPIO15), `RX` to the Pi's `TX` (GPIO14), and the `PPS` output to **GPIO4, physical pin 7**. The active antenna ships in the same box and reaches the board on a 170 mm lead, which is the real constraint on where it can go: take the receiver outside or put the antenna against a window and the board beside it. A cold start with a clear sky view takes 30 to 90 seconds; indoors under a roof it may never lock at all, and that is the single most common cause of "PPS is not working".

Tell the kernel the PPS pin exists by adding this line to `/boot/firmware/config.txt`, then reboot:

```
dtoverlay=pps-gpio,gpiopin=4
```

**Verify, part one.** The kernel sees pulses:

```bash
sudo ppstest /dev/pps0
```

Expected: a line roughly once per second, with the `sequence` number incrementing by exactly 1 each time. If it prints `timed out`, the receiver has no satellite fix (check the receiver's own lock LED) or GPIO4 (pin 7) is not connected. If sequence numbers jump by more than 1, you have a marginal antenna position.

Now point chrony at it. Add to `/etc/chrony/chrony.conf`:

```
refclock PPS /dev/pps0 refid PPS lock NMEA prefer
refclock SHM 0 refid NMEA offset 0.200 delay 0.2 stratum 3
makestep 1.0 3
```

Restart chrony and give it five minutes to settle. It genuinely needs the five minutes; judging it earlier will tell you it is broken when it is merely young.

**Verify, part two.** The clock is disciplined to the pulse, not the network:

```bash
chronyc sources -v && chronyc tracking | grep -E 'Reference ID|RMS offset'
```

Expected: `PPS` marked with `*` in `chronyc sources` (the selected source), a `Reference ID` containing `PPS`, and an `RMS offset` below `0.000001` seconds, which is one microsecond. If the reference ID names a network server instead, chrony has not accepted the PPS source; the usual cause is that the NMEA reference is missing, since chrony will not lock to a bare pulse train with no idea which second it belongs to.

The node reads exactly this output to grade its own clock. If it says PPS here, the archive will record `gnss_pps` and your data can be combined with other nodes'. If it says anything else, it will honestly record that instead.

## Step 4: Install the node agent

```bash
git clone https://github.com/Xaxis/nband.git ~/nband
cd ~/nband/firmware
python3 -m venv ~/.nband-venv
~/.nband-venv/bin/pip install -e '.[pi]'
```

**Verify.** The agent imports and reports the version the docs were written against:

```bash
~/.nband-venv/bin/python -c "import nband_node; print(nband_node.__version__)"
```

Expected: `0.1.0`, matching the version stamped at the top of this page. A mismatch means the documentation and the firmware have drifted, which is a bug worth reporting rather than working around.

## Step 5: Run in simulation before touching a sensor

Prove the whole pipeline works before adding hardware that can fail. Simulation mode drives every configured channel from a synthetic source shaped like the real instrument.

```bash
cp config.example.toml ~/node.toml
~/.nband-venv/bin/python -m nband_node.agent \
  --config ~/node.toml --simulate --self-test
```

**Verify.** Every channel reports `PASS` with a plausible value in its own units. Then run the loop for a minute and confirm it is writing:

```bash
~/.nband-venv/bin/python -m nband_node.agent \
  --config ~/node.toml --simulate --spool /tmp/spool --key /tmp/node.key --duration 60
wc -l /tmp/spool/telemetry.ndjson
```

Expected: a non-zero line count, and `head -1 /tmp/spool/telemetry.ndjson` shows a JSON object with `channel_id`, `band`, `t_ns`, and `q`. If `q` is `1`, the clock is flagged degraded, which is correct in simulation and should become `0` once you run against real hardware with PPS locked.

You now have a working node in every respect except that it is imagining its data. Everything from here is replacing imagination with sensors.

## Step 6: First real sensor, on I2C

Start with the environmental sensor. It is cheap, it is hard to damage, and it is the easiest way to prove the I2C path works before you put a USD 329 thermal camera on the same bus.

Wire the BME688: `VIN` to 3.3 V, `GND` to ground, `SCL` to GPIO3, `SDA` to GPIO2.

**Verify.** The device answers on the bus:

```bash
i2cdetect -y 1
```

Expected: `77` (or `76`) appears in the grid. If the grid is entirely blank, check power and that SDA and SCL are not swapped. If every cell reads `00`, you have a short.

Now edit `~/node.toml`, remove the channels you do not have yet, and leave the two `env` channels. Run the self-test again:

```bash
~/.nband-venv/bin/python -m nband_node.agent --config ~/node.toml --self-test
```

Expected: `env.temp` reads within a few degrees of the room and `env.pressure` reads between 950 and 1050 hPa. A pressure reading near 26 hPa means the driver is reading the wrong register; a temperature reading above 50 °C usually means the sensor is sitting on top of the Pi's SoC and needs moving.

## Step 7: Add the cameras

Connect the HQ camera to `CAM0` with the ribbon contacts facing away from the Ethernet jack. Ribbon orientation is the cause of most "camera not detected" reports.

**Verify.** The stack sees it, and you can take a picture you can actually look at:

```bash
rpicam-hello --list-cameras
rpicam-still -o /tmp/test.jpg --immediate
```

Expected: the camera is listed with its sensor name (`imx477`), and `/tmp/test.jpg` exists and is more than 100 kB. Copy it off the Pi and look at it. A uniformly grey frame means the lens cap is on or the aperture is closed; both are more common than a broken sensor.

If you are fitting the second, infrared camera, put the 850 nm bandpass filter in front of it now. **Without the filter this is not a near-infrared channel**, it is a second visible-light channel with extra noise, and the grid will treat any data you send from it as a duplicate rather than as an independent band.

## Step 8: Close the box

Everything so far has run on a bench with the sensors in open air, which is the right way to find a miswired one and the reason this step is easy to underestimate. The enclosure is not packaging. A weatherproof box is a wall, most of these bands cannot cross a wall, and a node that was correct on the bench will read the inside of its own lid once the lid is on and report that as sky.

The aperture table under [Enclosure on the hardware page](/hardware#enclosure) states what each case has to let through and what every window is made of, and there is a dimensioned drawing beside it placing each window on the part that looks through it. Cut or print to that drawing rather than to a hole saw you already own: the window positions come from the same packing rule that decides where the sensors sit, so a hole moved for convenience is a sensor looking at plastic.

Three of those materials are worth restating here, because they are the ones people substitute. The thermal window is germanium, and nothing cheap replaces it, since glass, acrylic and every printable filament are opaque between 8 and 14 micrometres. The ultraviolet window is fused silica, because glass and standard acrylic cut off somewhere between 350 and 400 nm and the sensor behind either of them still returns numbers. The short-wave window is fused silica rather than the acrylic that serves the visible cameras, which is the trap waiting in a tier 3 build: the cheapest window in the box is opaque to the most expensive sensor in it.

Three things about fitting the sensors that a plan view cannot show. Mount the thermal sensor against its window rather than behind a standoff, because a 110 degree field of view vignettes fast on a 25 mm aperture held away from it. Face the acoustic port down, or into the lee, since a port facing the sky is a drain and a port facing the wind is a microphone recording the wind. Put the environmental sensor at the vent rather than beside the Pi, which is the warmest object in the box and will otherwise be the thing it measures.

Fit the breather vent before you close anything, and put reusable desiccant in beside the electronics. A sealed enclosure traps moisture rather than excluding it: the air you shut the lid on is as humid as the room it was in, and the first cold night condenses it onto the coldest surface in the box, which is always the optics. The vent is not a hole in the waterproofing, it is what makes the waterproofing work, because a box that cannot equalise as it warms and cools pulls water in through whatever imperfection it has.

Do not drill anything for the navigation, radio or radar channels. All three read through a copolymer polypropylene or unfilled ASA wall, and the registry records that as an aperture precisely because the absence of a hole is the load-bearing part. The two ways to lose those three bands are substituting a metal case and printing in carbon-filled filament, and both look like reasonable choices at the time.

**Verify, part one.** The wall still passes what it is supposed to pass. Close the lid on a node that had PPS lock in step 3, leave it five minutes, then:

```bash
chronyc tracking | grep -E 'Reference ID|RMS offset'
```

Expected: the same reference ID and roughly the same offset as before the lid went on. A `Reference ID` that stops naming `PPS` when the box closes is a conductive wall rather than a failed receiver, and no window will fix it.

**Verify, part two.** Each optical channel is looking through its window rather than at it. Run the self-test with the box closed, hold a warm hand flat against the thermal window, and run it again:

```bash
~/.nband-venv/bin/python -m nband_node.agent --config ~/node.toml --self-test
```

Expected: `lwir.main` moves by several kelvin between the two readings and settles back afterwards. This is the one failure in the build that produces a plausible number instead of an error. A Lepton behind acrylic reports a steady field at about indoor temperature, every channel still says `PASS`, and the archive fills with a careful measurement of the underside of a lid. The reading changing is the only evidence you get that the window passes 8 to 14 micrometres. If you fitted the ultraviolet channel, the equivalent test is that it reads near zero indoors and rises by orders of magnitude in direct sun; behind ordinary glass it will rise a little, and that little is UVA getting through and being recorded as the band.

**Verify, part three.** The environmental channel is measuring the outside and not the box. Leave the closed node outdoors for an hour, then run the self-test again.

Expected: `env.temp` within a couple of degrees of the outside air. Do not check this against a weather report, because those pressures are corrected to sea level and your sensor is not: at 300 metres the two legitimately differ by about 35 hPa, and chasing that difference has cost people an afternoon. What proves the vent is working is that temperature tracks the outside air instead of lagging it by tens of minutes, and that pressure moves at all across a day. A channel that sits high and barely changes is reading a sealed box, which means the vent is blocked, the membrane went on over the sensor rather than beside it, or the sensor is sitting in the Pi's exhaust.

## Step 9: Survey your horizon

The node needs to know what it physically cannot see. Without this, "nothing detected to the north" is ambiguous between a clear sky and a ridgeline.

Stand at the node position with a compass and a clinometer, or a phone app that does both. At each of the eight compass points, record the elevation angle above which sky is actually visible. Put those numbers in the `[site.horizon_mask]` table in `~/node.toml`.

**Verify.** The config still loads, which proves the table is well-formed:

```bash
~/.nband-venv/bin/python -m nband_node.agent --config ~/node.toml --self-test
```

A malformed mask fails loudly at startup rather than silently defaulting to an unobstructed sky.

### Disable the pull-ups on your I2C breakouts

Nearly every breakout board ships with its own I2C pull-up resistors fitted, usually 10 k, and nearly every one of them has a jumper or a solder pad to remove them. Remove them on all but one.

The Raspberry Pi fits 1.8 k pull-ups to 3V3 on GPIO2 and GPIO3 on the board itself, and those cannot be removed. That value is correct on its own, which is why the carrier fits none of its own. Four breakouts left as shipped bring the bus to about 1,047 ohms, which still works. What does not work is adding more: I2C needs at least (3.3 - 0.4) / 3 mA, about 967 ohms, to pull a valid low, and it is easy to go under that without noticing because the symptom is not a dead bus. It is a bus that works until a hot afternoon or a longer cable, and then produces read errors that look like a failing sensor.

## Step 10: Enrol with the grid

Enrolling a new node needs a secret, and there is no self-service way to get one yet. Ask for it: open an issue on the repository titled "node enrolment", or email the address in [SECURITY.md](https://github.com/Xaxis/nband/blob/main/SECURITY.md). Say roughly where the node will be and which tier you built. You will get a secret back.

That gate exists because the archive's only real asset is that its contents are trustworthy, and an open write endpoint is an open invitation to poison it. It is a deliberate bottleneck rather than a permanent policy, and it will be replaced by something self-service once there is a reviewed way to admit a node without a human in the loop.

You do not need a secret to develop against the grid. `--simulate` runs the whole agent against synthetic data, and a simulated node's data is excluded from the public feed and can never reach a verdict, so you can exercise every code path before asking anyone for anything.

Set your node's slug, position, and the enrolment secret in `~/node.toml`, then:

```bash
~/.nband-venv/bin/python -m nband_node.agent --config ~/node.toml --enroll
```

**Verify.** The response contains a `node_id`, the channel count you expect, and a `published_position` that is **not** your exact coordinates. The published point sits somewhere inside a disc of the radius you declared, a random place inside it, not a fixed distance away, and the direction is derived from a secret the grid server holds, so it cannot be recomputed and subtracted by someone reading this page. Your home address does not appear on a public map.

Check the published point on a map before continuing. If it lands somewhere you would rather it did not, raise `location_precision_m` and re-enrol; the offset is recomputed from the new radius. If you are in a sparsely populated area, consider that a one-kilometre disc may still contain only a handful of buildings, and set the precision accordingly.

Your node key was generated on first run at the path in `[grid].key_path` and is `0600`. It never leaves the machine. Back it up somewhere safe: losing it means enrolling under a new slug, and the archive cannot connect the two.

## Step 11: Run it for real

Everything so far has run as you, out of your home directory, because that is the fastest way to find a miswired sensor. The service does not run that way. It runs as an unprivileged `nband` user with `ProtectHome=true`, which means it cannot read your home directory at all, not the venv, not the config, not the key. So installing it is a real step rather than a file copy:

```bash
sudo ~/nband/firmware/install.sh
```

That creates the `nband` service account, builds `/opt/nband/venv`, copies your config to `/etc/nband/node.toml` with the paths rewritten, moves your node key to `/var/lib/nband/node.key` so the service can reach it, installs the unit, and starts it. Run it again any time you change your config. If your config is not at `~/node.toml`, pass the path as an argument.

Back up `/var/lib/nband/node.key` before you delete the copy in your home directory. Losing it means enrolling under a new slug, and the archive cannot connect the two.

**Verify.** The service is running, the clock is disciplined, and the grid has heard from you:

```bash
systemctl status nband-node --no-pager
journalctl -u nband-node -n 20 --no-pager
```

Expected: `active (running)`, a startup line reporting your channel and band count, and `clock=gnss_pps`. If it reports `clock=freerun` or `clock=ntp`, go back to step 3; the node will still record, but its data will be marked as unable to contribute to multi-node geometry.

Then open the node's page on the grid and confirm telemetry is arriving. First data usually appears within a minute of the first upload interval.

## What to do when it does not work

The spool is the first place to look. If `/var/lib/nband/spool/telemetry.ndjson` is growing but the grid shows nothing, the node is recording and the upload is failing, which is a network or credential problem rather than a sensor one. Check `journalctl` for `upload failed`. The node is designed to keep recording through outages and backfill later, so a few hours of failed uploads costs nothing as long as the disk holds.

If the spool is not growing, no channel is producing samples. Run `--self-test` to find which one.

If a channel reports wildly wrong values, check its `unit` in the config against what the driver actually returns. A unit mismatch does not crash anything; it quietly poisons the archive, which is worse.

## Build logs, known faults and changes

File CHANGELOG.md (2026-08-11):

# Changelog

Notable changes to the platform. Because hardware, firmware, database, and
documentation ship on one version, an entry here can affect all four.

The format follows [Keep a Changelog](https://keepachangelog.com/en/1.1.0/).
Versions are the value in `VERSION`, which every document declares itself
written against and which `make drift` enforces.

## [Unreleased]

### Changed
- Renamed from BIFROST to **nband**, with the domain **nband.space**. The
  Postgres schema, Python packages, npm workspace, HTTP headers, environment
  variables, filesystem paths, and CLI all moved with it.
- **Breaking (wire protocol).** Ingest signatures now cover the request path, a
  timestamp, and a single-use nonce in addition to the body. Nodes must send
  `X-Nband-Timestamp` and `X-Nband-Nonce`; requests older than five minutes or
  replaying a nonce are refused. Older agents cannot write to the grid.
- Tier budgets are restated from the sourced part prices rather than aspiration,
  and a drift check keeps them honest. Tiers now cost $460 / $1,650 / $5,228.
- The GNSS pulse-per-second input moved from GPIO18 to **GPIO4, physical pin 7**.
  GPIO18 is the I2S bit clock and was claimed by the microphone on any node
  carrying both. Existing builds must move one wire and update `config.txt`.
- `NoiseFloor` forgets exponentially instead of averaging over a node's whole
  lifetime, so thresholds follow a channel's diurnal cycle instead of sitting
  between day and night.

### Fixed
- **Row level security stopped at the telemetry partitions.** Every policy the
  archive relies on was attached to `nband.telemetry`, the partitioned parent,
  and none of them to the partitions underneath it. Postgres applies the
  parent's policy only when the parent is the table being queried, so a
  partition named directly answered with every row it held, including samples
  from simulated and non-public nodes that 0004 and 0005 exist to withhold.
  Migration 0002 compounded it by granting `select` on each new partition to
  `anon` and `authenticated`, grants that were never needed because permission
  for a partitioned read is checked on the parent alone. Nothing was served:
  PostgREST does not route to partitions, so the Data API never exposed them.
  That is one component's behaviour rather than a guarantee this schema made.
  Migration 0010 enables RLS with no policy on every partition, which denies
  direct access outright, drops the grants, and adds an event trigger so a
  partition created by the ingest path or by hand is secured on creation rather
  than on remembering. Verified against the live database: a read through the
  parent still returns its rows, and a direct partition read is refused.
- **Published node positions could be de-fuzzed to about five metres.** The
  offset's bearing was derived by hashing the node's Ed25519 public key, which
  was itself a column on the world-readable `nodes` row, so anyone could
  recompute the offset and subtract it. The distance was always exactly
  `location_precision_m`, placing every node on a known circle rather than
  anywhere inside a disc — a 1 km precision meant a 0.14 km² annulus instead of
  3.1 km². Four pages promised operators the opposite. The offset is now an
  HMAC over a server-only `NBAND_FUZZ_SALT`, the radius is drawn as
  `precision × √u` so the point is uniform over the disc, the public key is no
  longer granted to the anonymous role, and `make privacy` measures the
  resulting distribution rather than asserting it in a comment. No operator was
  affected: the node table was empty and the feed was still mock.
- **The americium-241 dose "correction" was wrong by two orders of magnitude**,
  in the alarming direction, and stood on the live safety page. A tabulated
  constant of 3.2 × 10⁻² mGy·m²/(GBq·h) was published as "3.2 µSv/h per MBq" —
  the mGy→µGy and GBq→MBq conversions cancel, so the only error was the dropped
  10⁻², a factor of exactly one hundred.
  The real figure is 1–28 nSv/h at one metre depending on whether the soft
  neptunium L X-rays are counted, against a 340 nSv/h background — a few
  percent of background, never three times it. The retracted original was
  approximately right. The accompanying claim that 2 mm of aluminium does not
  help was also wrong. The module stays withdrawn: 10 CFR 30.15 was always the
  real reason and is sufficient on its own.
- **The node agent never graded its own clock.** It asserted `gnss_pps` with a
  fabricated offset on every real run, so the strongest gate on the
  classification ladder was a constant in production and a free-running node
  could contribute to cross-node geometry.
- **Nanosecond timestamps lost up to 999 microseconds** on ingest. The
  timestamp was built with millisecond-resolution `Date`, while the schema
  documentation promised a lossless round trip. It is lossless now.
- **Catalogue checks that could not be performed were recorded as clean.** An
  event with no bearing was treated as though ADS-B had cleared it.
- Three of the eight declared catalogues had no implementation, so an event
  could reach `unresolved` having silently skipped meteor showers, space
  weather, and airspace notices.
- Simulated data was publicly readable through events, verdicts, catalogue
  checks, artifacts, and heartbeats despite being flagged.
- The coincidence detector bounded its window on one side only, and a solo
  detection left its trigger pending so one crossing could be counted twice.
- `ChannelConfig.calibration` did not exist; two drivers raised
  `AttributeError` on every real node.
- The systemd unit set `WatchdogSec` with nothing sending notifications, which
  would SIGABRT a healthy node every five minutes.
- The spool rewrote itself non-atomically, and a single truncated line wedged
  the agent permanently.
- `--ink-3` failed WCAG AA against every surface in both themes.
- Every page shared one Open Graph title, so any shared link claimed to be the
  homepage.
- The spectrum axis placed acoustic and seismic channels on the electromagnetic
  wavelength scale, converting sound frequency with the speed of light.

### Corrected
Claims that were wrong, and wrong in the reassuring direction:
- **10 CFR 30.15** was described as a general-license threshold covering a 9 µCi
  aggregate. It is an exemption, limited to 1 µCi **per detector** in an intact
  fire-protection device. The aggregated source is withdrawn from the reference
  bill of materials.
- **FCC Part 15** has no 100 mW allowance at 400–600 MHz; that band is not ISM
  and §15.209 limits field strength to nearer nanowatts. The broadband emitter
  is withdrawn.
- The **americium-241 dose figure** was restated as roughly 1,070 nSv/h at one
  metre, "about three times natural background". **This correction was wrong**
  and is itself retracted below. The dose was never the reason the
  module was withdrawn; 10 CFR 30.15 was, and that part of the entry stands.

### Added
- Site search over pages, document sections, bands, parts, and concepts.
- Interactive discriminator that runs the real scoring logic, held to the Python
  engine by a conformance check.
- Wiring, pinout, and power-budget diagrams generated from the hardware registry.
- Band-versus-phenomenon detection matrix and atmospheric transmission curve.
- 3D hero scene showing detection shells at their real schema ranges.
- Replay protection, `make` as a single entry point, and this changelog.

## [0.1.0] — 2026-07-27

Initial platform: canonical schema, grid database, node agent, discriminator,
ingest API, and the documentation site.

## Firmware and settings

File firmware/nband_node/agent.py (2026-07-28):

"""The node agent: sample, trigger, spool, upload.

Offline-first by construction. A node on a desert mast with intermittent
Starlink is the design case, not the edge case, so nothing is discarded because
the link is down. Samples go to a local append-only spool first and are removed
only once the grid has acknowledged them. When the spool reaches its configured
ceiling the oldest *context* data is dropped before any detection is touched,
because losing an hour of barometric pressure costs almost nothing and losing a
detection costs the whole point of the exercise.

Every batch is signed with the node's Ed25519 key. The key is generated on the
node and never leaves it, so the grid can verify that telemetry attributed to a
node actually came from it.
"""

from __future__ import annotations

import argparse
import contextlib
import json
import logging
import os
import queue
import secrets
import shutil
import signal
import subprocess
import sys
import threading
import time
import urllib.error
import urllib.request
from base64 import urlsafe_b64encode
from dataclasses import asdict
from pathlib import Path

from . import config as configmod
from . import sensors
from .core import (
    ChannelTrigger,
    Clock,
    CoincidenceDetector,
    Detection,
    NoiseFloor,
    RingBuffer,
    Sample,
)
from .schema_generated import PLATFORM_VERSION, SCHEMA_VERSION, ClockQuality

log = logging.getLogger("nband")


def sd_notify(message: str) -> None:
    """Send a readiness or watchdog ping to systemd, if it is listening.

    The unit file declares Type=notify and WatchdogSec=300. Without these
    messages systemd concludes the agent never started, and then that it has
    hung, and SIGABRTs a perfectly healthy node every five minutes. No
    dependency: it is a datagram to the socket in NOTIFY_SOCKET.
    """
    addr = os.environ.get("NOTIFY_SOCKET")
    if not addr:
        return
    try:
        import socket

        # A leading '@' denotes the abstract namespace.
        path = "\0" + addr[1:] if addr.startswith("@") else addr
        with socket.socket(socket.AF_UNIX, socket.SOCK_DGRAM) as sock:
            sock.connect(path)
            sock.sendall(message.encode())
    except OSError as exc:
        log.debug("sd_notify failed: %s", exc)


class GridError(RuntimeError):
    """The grid rejected a request and said why."""


# ---------------------------------------------------------------------------
# Identity
# ---------------------------------------------------------------------------


class Identity:
    """Ed25519 node identity."""

    def __init__(self, key_path: Path) -> None:
        self.key_path = key_path
        self._private = self._load_or_create()

    def _load_or_create(self):
        try:
            from cryptography.hazmat.primitives.asymmetric.ed25519 import Ed25519PrivateKey
        except ImportError as exc:  # pragma: no cover
            raise SystemExit(
                "nband: the 'cryptography' package is required for node identity.\n"
                "  pip install cryptography"
            ) from exc

        if self.key_path.exists():
            return Ed25519PrivateKey.from_private_bytes(self.key_path.read_bytes())

        key = Ed25519PrivateKey.generate()
        self.key_path.parent.mkdir(parents=True, exist_ok=True)
        # Written 0600 before any bytes land on disk.
        fd = os.open(self.key_path, os.O_WRONLY | os.O_CREAT | os.O_EXCL, 0o600)
        with os.fdopen(fd, "wb") as fh:
            from cryptography.hazmat.primitives import serialization

            fh.write(
                key.private_bytes(
                    encoding=serialization.Encoding.Raw,
                    format=serialization.PrivateFormat.Raw,
                    encryption_algorithm=serialization.NoEncryption(),
                )
            )
        log.info("generated new node key at %s", self.key_path)
        return key

    @property
    def public_key_b64(self) -> str:
        from cryptography.hazmat.primitives import serialization

        raw = self._private.public_key().public_bytes(
            encoding=serialization.Encoding.Raw, format=serialization.PublicFormat.Raw
        )
        return urlsafe_b64encode(raw).decode().rstrip("=")

    def sign(self, payload: bytes) -> str:
        return urlsafe_b64encode(self._private.sign(payload)).decode().rstrip("=")


# ---------------------------------------------------------------------------
# Spool
# ---------------------------------------------------------------------------


class Spool:
    """Append-only local buffer, newline-delimited JSON.

    Two files so that pressure on the disk never costs a detection: telemetry
    is expendable, detections are not.
    """

    def __init__(self, directory: Path, max_bytes: int) -> None:
        self.dir = directory
        self.dir.mkdir(parents=True, exist_ok=True)
        self.telemetry = self.dir / "telemetry.ndjson"
        self.detections = self.dir / "detections.ndjson"
        self.max_bytes = max_bytes

    def append(self, path: Path, record: dict) -> None:
        with path.open("a", encoding="utf-8") as fh:
            fh.write(json.dumps(record, separators=(",", ":")) + "\n")

    def size(self) -> int:
        return sum(p.stat().st_size for p in (self.telemetry, self.detections) if p.exists())

    def enforce_ceiling(self) -> None:
        """Drop the oldest telemetry when over budget. Detections are never cut."""
        if self.size() <= self.max_bytes or not self.telemetry.exists():
            return
        lines = self.telemetry.read_text(encoding="utf-8").splitlines()
        keep = lines[len(lines) // 2 :]
        self.telemetry.write_text("\n".join(keep) + ("\n" if keep else ""), encoding="utf-8")
        log.warning(
            "spool over %d bytes: dropped %d oldest telemetry records",
            self.max_bytes,
            len(lines) - len(keep),
        )

    def drain(self, path: Path, limit: int) -> list[dict]:
        """Read up to `limit` records, skipping any line that will not parse.

        A node loses power mid-write eventually, leaving a truncated final line.
        Letting json.loads raise here wedged the agent permanently: every flush
        hit the same bad line and no record after it could ever be delivered.
        """
        if not path.exists():
            return []
        out: list[dict] = []
        with path.open(encoding="utf-8") as fh:
            for line in fh:
                if len(out) >= limit:
                    break
                line = line.strip()
                if not line:
                    continue
                try:
                    out.append(json.loads(line))
                except json.JSONDecodeError:
                    log.warning("skipping unparseable spool line in %s", path.name)
                    out.append({"__unparseable__": True})
        return out

    def commit(self, path: Path, count: int) -> None:
        """Remove the first `count` records after the grid has acknowledged them.

        Written to a temporary file and renamed. The previous version truncated
        and rewrote in place, so losing power mid-write destroyed the entire
        remaining spool rather than a single record. rename() within a directory
        is atomic on POSIX, so a crash leaves either the old file or the new one.
        """
        if not path.exists() or count <= 0:
            return
        lines = path.read_text(encoding="utf-8").splitlines()
        rest = lines[count:]
        tmp = path.with_suffix(path.suffix + ".tmp")
        with tmp.open("w", encoding="utf-8") as fh:
            fh.write("\n".join(rest) + ("\n" if rest else ""))
            fh.flush()
            os.fsync(fh.fileno())
        os.replace(tmp, path)


# ---------------------------------------------------------------------------
# Uploader
# ---------------------------------------------------------------------------


class GridClient:
    def __init__(self, cfg: configmod.GridConfig, identity: Identity) -> None:
        self.cfg = cfg
        self.identity = identity

    def _post(self, path: str, body: dict, timeout: float = 20.0) -> dict:
        payload = json.dumps(body, separators=(",", ":")).encode()

        # The signature covers the path, a timestamp, and a single-use nonce as
        # well as the body. Signing the body alone left every request valid
        # forever and replayable on any endpoint, which is enough to fabricate
        # archive content: replayed detections become distinct events because
        # each insert mints a fresh id.
        timestamp = str(int(time.time()))
        nonce = secrets.token_urlsafe(18)
        canonical = b"nband/v1\n%s\n%s\n%s\n%s" % (
            path.encode(),
            timestamp.encode(),
            nonce.encode(),
            payload,
        )

        req = urllib.request.Request(
            f"{self.cfg.endpoint}{path}",
            data=payload,
            headers={
                "Content-Type": "application/json",
                "X-Nband-Node": self.cfg.node_slug,
                "X-Nband-Key": self.identity.public_key_b64,
                "X-Nband-Signature": self.identity.sign(canonical),
                "X-Nband-Timestamp": timestamp,
                "X-Nband-Nonce": nonce,
                "X-Nband-Schema": SCHEMA_VERSION,
                "User-Agent": f"nband-node/{PLATFORM_VERSION}",
            },
            method="POST",
        )
        try:
            with urllib.request.urlopen(req, timeout=timeout) as resp:
                return json.loads(resp.read() or b"{}")
        except urllib.error.HTTPError as exc:
            # The grid returns a JSON body explaining every rejection. Losing it
            # leaves an operator staring at a bare status code, which is the
            # least actionable thing a network client can do.
            detail = exc.read().decode(errors="replace")
            try:
                parsed = json.loads(detail)
                msg = parsed.get("error", detail)
                extra = parsed.get("detail")
                raise GridError(
                    f"{exc.code} {msg}" + (f" :: {json.dumps(extra)}" if extra else "")
                ) from None
            except json.JSONDecodeError:
                raise GridError(f"{exc.code} {detail[:400]}") from None

    def enroll(self, cfg: configmod.NodeConfig) -> dict:
        return self._post(
            "/api/grid/register",
            {
                "slug": cfg.grid.node_slug,
                "display_name": cfg.node_name,
                "tier": cfg.tier.value,
                "pubkey": self.identity.public_key_b64,
                "enrollment_secret": cfg.grid.enrollment_secret,
                "firmware_version": PLATFORM_VERSION,
                "schema_version": SCHEMA_VERSION,
                # The node knows whether it is inventing its data, so it says
                # so rather than leaving the grid to guess. Simulated nodes are
                # excluded from the public feed and never reach a verdict.
                "is_simulated": cfg.simulate,
                "site": {
                    "lat": cfg.site.latitude,
                    "lon": cfg.site.longitude,
                    "elevation_m": cfg.site.elevation_m,
                    "location_precision_m": cfg.site.location_precision_m,
                    "horizon_mask": cfg.site.horizon_mask,
                },
                "channels": [
                    {
                        "channel_id": c.channel_id,
                        "band": c.band.value,
                        "unit": c.unit,
                        "sample_rate_hz": c.sample_rate_hz,
                        "part_id": c.part_id,
                        "azimuth_deg": c.azimuth_deg,
                        "elevation_deg": c.elevation_deg,
                        "fov_deg": c.fov_deg,
                        "role": "context" if c.is_context else "detection",
                    }
                    for c in cfg.channels
                    if c.enabled
                ],
            },
        )

    def send_telemetry(self, records: list[dict]) -> bool:
        try:
            self._post("/api/grid/telemetry", {"samples": records})
            return True
        except (GridError, urllib.error.URLError, OSError, TimeoutError) as exc:
            log.warning("telemetry upload failed, keeping spool: %s", exc)
            return False

    def send_detections(self, records: list[dict]) -> bool:
        try:
            self._post("/api/grid/detections", {"detections": records})
            return True
        except (GridError, urllib.error.URLError, OSError, TimeoutError) as exc:
            log.warning("detection upload failed, keeping spool: %s", exc)
            return False

    def heartbeat(self, body: dict) -> None:
        try:
            self._post("/api/grid/heartbeat", body, timeout=10.0)
        except (GridError, urllib.error.URLError, OSError, TimeoutError) as exc:
            log.debug("heartbeat failed: %s", exc)


# ---------------------------------------------------------------------------
# Channel workers
# ---------------------------------------------------------------------------


class ChannelWorker(threading.Thread):
    """Reads one channel on its own thread and posts samples to a queue.

    Every driver read used to happen inline on the single main loop, so any
    channel that blocked blocked all of them. That is not a hypothetical: an
    SDR read is tens of milliseconds, a camera capture can be hundreds, and a
    serial read sits on its timeout when the sensor is unplugged. One unplugged
    UART could stall a node's optical channels indefinitely, and the resulting
    gaps would look like quiet sky rather than a wiring fault.

    Each worker owns its own driver and its own cadence. A slow channel now
    delays only itself.
    """

    def __init__(
        self,
        channel: configmod.ChannelConfig,
        driver: sensors.Driver,
        out: queue.Queue[Sample],
        clock: Clock,
        stop: threading.Event,
    ) -> None:
        super().__init__(name=f"ch-{channel.channel_id}", daemon=True)
        self.channel = channel
        self.driver = driver
        self.out = out
        self.clock = clock
        # NOT `self._stop`: threading.Thread has an internal _stop() that join()
        # calls, and shadowing it with an Event makes every join raise
        # TypeError after the thread has already done its work.
        self._halt = stop
        #: Samples discarded because the queue was full. Reported in heartbeats
        #: rather than silently lost, because a node dropping data should say so.
        self.dropped = 0
        self.failures = 0

    def run(self) -> None:
        interval = 1.0 / self.channel.sample_rate_hz
        next_read = time.monotonic()
        while not self._halt.is_set():
            now = time.monotonic()
            if now < next_read:
                # Sleep in slices so shutdown is prompt even on a 0.1 Hz channel.
                self._halt.wait(min(next_read - now, 0.25))
                continue
            next_read = now + interval
            try:
                sample = self.driver.read(self.clock.now_ns())
            except Exception as exc:
                self.failures += 1
                log.error("channel %s read failed: %s", self.channel.channel_id, exc)
                # Back off so a hard-failing driver cannot spin the CPU.
                self._halt.wait(1.0)
                continue
            if sample is None:
                continue
            try:
                self.out.put_nowait(sample)
            except queue.Full:
                # Bounded on purpose: the memory budget is the whole reason
                # tier 1 fits a 2 GB board. Dropping the newest sample keeps the
                # backlog ordered, and the count surfaces in the heartbeat.
                self.dropped += 1


# ---------------------------------------------------------------------------
# Agent
# ---------------------------------------------------------------------------
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

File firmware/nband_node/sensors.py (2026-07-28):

"""Sensor drivers.

Every band is behind one interface. That is what lets the grid treat a USD 75
thermal array and a USD 329 radiometric camera as the same band while still
knowing the difference: the driver declares its own capabilities, and the
discriminator reads those capabilities rather than assuming them.

Real hardware imports are all optional and local to the driver that needs them.
A node with no thermal camera does not need the thermal library installed, and
a laptop running `--simulate` needs none of them. Every driver has a simulated
twin so the entire pipeline is exercisable before any hardware arrives, which
is also how the build guide lets you verify each step.
"""

from __future__ import annotations

import datetime
import math
import time
from abc import ABC, abstractmethod
from collections.abc import Callable
from dataclasses import dataclass

from .config import ChannelConfig
from .core import Q_CALIBRATION_STALE, Q_CLOCK_DEGRADED, Q_SATURATED, Q_SELF_EMISSION, Sample
from .schema_generated import Band


@dataclass(frozen=True)
class Capabilities:
    """What a driver can actually resolve.

    This is the honest-substitution mechanism. Two thermal drivers both report
    band `lwir`, but only one reports `radiometric=True` and a useful
    `resolution`. The discriminator scores thermal morphology only when the
    driver claims it can resolve morphology, so registering a cheaper part
    degrades the analysis gracefully instead of corrupting it.
    """

    radiometric: bool = False
    resolution: tuple[int, int] | None = None
    #: Absolute accuracy in the channel's unit, where the datasheet states one.
    accuracy: float | None = None
    #: True when the driver periodically blanks its own stream (thermal
    #: flat-field shutters do this) and marks those samples invalid.
    self_interrupting: bool = False
    notes: str = ""


class Driver(ABC):
    """Base sensor driver."""

    #: Band this driver produces. Set by subclasses.
    band: Band

    def __init__(self, channel: ChannelConfig) -> None:
        self.channel = channel
        self._opened = False

    @property
    def channel_id(self) -> str:
        return self.channel.channel_id

    def capabilities(self) -> Capabilities:
        return Capabilities()

    def open(self) -> None:
        self._opened = True

    def close(self) -> None:
        self._opened = False

    @abstractmethod
    def read(self, t_ns: int) -> Sample | None:
        """Return one sample, or None if no reading is available right now."""

    def self_test(self) -> tuple[bool, str]:
        """Used by the build guide. Every step ends in something verifiable."""
        try:
            self.open()
            s = self.read(time.time_ns())
        except Exception as exc:
            return False, f"{type(exc).__name__}: {exc}"
        finally:
            self.close()
        if s is None:
            return False, "driver opened but produced no sample"
        return True, f"{s.value:g} {self.channel.unit}"


# ---------------------------------------------------------------------------
# Simulated drivers
# ---------------------------------------------------------------------------


def _solar_elevation(t_ns: int, lon: float) -> float:
    """Crude solar proxy, -1 at midnight to +1 at local noon."""
    day = (t_ns / 1e9) % 86_400
    local = (day + lon / 360 * 86_400) % 86_400
    return math.sin((local / 86_400 - 0.25) * 2 * math.pi)


class SimulatedDriver(Driver):
    """Synthetic source shaped like the real instrument.

    Each band's simulator reproduces the statistical character of the real
    sensor rather than generic noise: Poisson counting on the scintillator, a
    solar curve on the optical bands, an impulsive radio floor, the thermal
    shutter. A trigger pipeline tuned against generic noise will misbehave the
    first time it meets real data, so the simulator is deliberately awkward in
    the same ways the hardware is.
    """

    def __init__(self, channel: ChannelConfig, longitude: float = 0.0) -> None:
        super().__init__(channel)
        self.band = channel.band
        self._lon = longitude
        self._rng_state = abs(hash(channel.channel_id)) % (2**31)

    def _rand(self) -> float:
        # Deterministic LCG. Reproducible runs make bugs reproducible.
        self._rng_state = (1103515245 * self._rng_state + 12345) % (2**31)
        return self._rng_state / 2**31

    def _gauss(self) -> float:
        u1 = max(self._rand(), 1e-9)
        u2 = self._rand()
        return math.sqrt(-2 * math.log(u1)) * math.cos(2 * math.pi * u2)

    def capabilities(self) -> Capabilities:
        return Capabilities(notes="simulated source; not real measurement")

    def read(self, t_ns: int) -> Sample:
        b = self.band
        q = 0
        sun = _solar_elevation(t_ns, self._lon)

        if b is Band.GAMMA:
            lam = 38.0
            v = max(0.0, lam + self._gauss() * math.sqrt(lam))
        elif b is Band.UV:
            v = max(0.0, sun) ** 1.8 * 3400 + abs(self._gauss()) * 2
        elif b is Band.VIS:
            v = 9 + (1 - sun) * 4 if sun > 0 else 21.6 - abs(sun) * 0.5 + self._gauss() * 0.06
        elif b is Band.NIR:
            v = 120 + max(0.0, sun) * 2600 + self._gauss() * 14
        elif b is Band.LWIR:
            v = 243 + sun * 11 + self._gauss() * 0.4
            if int(t_ns / 1e9) % 180 == 0:
                q |= Q_CALIBRATION_STALE  # flat-field shutter
        elif b is Band.RF:
            impulse = 32.0 if self._rand() > 0.995 else 0.0
            v = -104 + self._gauss() * 1.6 + impulse
        elif b is Band.ELF_VLF:
            v = math.sin((t_ns / 1e9) / 13750) * 22 + self._gauss() * 6
        elif b is Band.ACOUSTIC:
            v = 28 + self._gauss() * 2 + (22 if self._rand() > 0.99 else 0)
        elif b is Band.MMW:
            r = self._rand()
            v = 2.0 if r > 0.99 else 1.0 if r > 0.94 else 0.0
        elif b is Band.SEISMIC:
            v = self._gauss() * 1e-7
        elif b is Band.ENV:
            # The env band carries several physically unrelated quantities, so
            # the simulator picks its curve from the declared unit. Emitting a
            # temperature curve for a pressure channel would produce readings
            # like 26 hPa, which is not a plausible barometer fault and would
            # quietly invalidate any test written against it.
            unit = self.channel.unit.lower()
            if "pa" in unit:
                v = 1013 + math.sin((t_ns / 1e9) / 1_146_000) * 4 + self._gauss() * 0.15
            elif "%" in unit or "rh" in unit:
                v = min(100.0, max(0.0, 45 - sun * 12 + self._gauss() * 1.5))
            else:
                v = 14 + sun * 12 + self._gauss() * 0.3
        elif b is Band.NAV:
            v = self._gauss() * 180
        else:
            v = self._gauss()

        return Sample(self.channel_id, b, t_ns, round(v, 4), q)
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

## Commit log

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2026-07-27 Implement missing drivers, discriminator CLI, and site essentials
    The audit found 13 drivers advertised in schema/hardware.json and
    config.example.toml with no implementation, including gnss_nmea_pps and
    rm3100. Build-guide step 6 tells people to run that config against real
    hardware, where it would have died with UnknownDriverError at exactly the
    point a builder has just soldered something and would blame their wiring.
    All 13 are now implemented, and firmware/tests/test_registry.py fails the
    build if a part ever advertises a driver that does not exist again.
    Discriminator CLI: reads unscored events, builds an Observation from the
    attached detections (taking the worst clock present, never i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
    [sensors.py]
2026-07-27 Generate wiring, pinout, and power diagrams from the registry
    Adds per-part electrical data to schema/hardware.json: continuous and idle
    draw, supply rail, and the physical header pins each sensor occupies. Four
    new visuals render from it, so swapping a part moves the diagrams rather than
    silently invalidating a hand-drawn picture.
    Node block diagram grouped by bus. A 40-pin header pinout with assignments
    resolved from the parts in the tier, using physical numbering because that is
    what you count on the board. A per-sensor wiring table. And a power budget
    with off-grid sizing. The pinout and wiring table also appear on /build,
    where someone actually has the soldering iron down.
    Having real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
2026-07-28 Add an interactive discriminator, held to the Python engine by a parity check
    The gates are far easier to believe when you can switch one off and watch the
    classification fall, so /discriminator now scores live as you change the bands,
    the clock, the node count, and each catalogue's availability.
    That required the scoring logic to exist in the browser as well as in Python,
    which is precisely the duplication this repository is built to prevent. So it
    is made checkable instead of trusted. Python stays authoritative;
    tools/gen-fixtures.py runs ten cases chosen to pin each gate through the real
    engine and records the results; tools/check-parity.mjs runs the same cases
    through the browser port a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
2026-07-28 Hero underlay with viewport takeover, and fix site-wide metadata
    The 3D scene now underlays the hero rather than sitting beside it, and the
    camera frames itself from the scene instead of a hard-coded position. The dome
    was clipped because the camera sat closer than the outermost shell's height
    required, and it clipped differently at every aspect ratio; as a wide, short
    underlay it clipped worst of all. Distance is now derived from the largest
    shell, the field of view, and the current aspect, so the volume fits at any
    size including expanded.
    Expand takes over the viewport rather than requesting browser fullscreen.
    Fullscreen hides the URL bar and page chrome, which is the wrong trade for a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
2026-07-28 Say what this is for, and label simulated data as simulated
    The copy hid behind instrument language and never stated the point. Choosing
    an instrument-first, cause-agnostic position means being rigorous about
    conclusions, not coy about the subject, and "most of the sky is invisible to
    you" was a true fact about human vision that had nothing to do with why anyone
    would build this.
    The hero now leads with the actual problem: thousands of reports a year and
    almost no evidence worth arguing about, because the recordings never contained
    the answer. One camera at unknown range cannot say whether a thing was
    enormous and distant or small and close, so the argument never ends. That is
    an instrument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
    [agent.py]
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2026-07-28 Fix hero framing, redraw the mark, normalise brand casing
    Screenshotting the deployed site for the first time exposed three things that
    building and type-checking could not.
    The camera framing was wrong in a way the previous fix had not addressed. It
    solved the trigonometry for a sphere of radius MAX_R, but the range rings lie
    on the ground plane, and viewed at a shallow elevation their near edge sits far
    closer to the camera than the far edge, so perspective stretched them well
    outside a sphere's silhouette. The dome fitted and the rings ran off both
    sides. Replaced with a binary search over camera distance that projects the
    outermost ring's extreme points and the dome apex and requires al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
    [agent.py, config.py]
2026-07-28 Fix a physics error on the spectrum axis, and stop trusting partial build output
    Screenshotting /bands exposed that the spectrum bar was placing the acoustic
    and seismic channels on the electromagnetic wavelength axis. Both have a
    frequency range in the schema, and the layout helper converted any frequency to
    a wavelength with the speed of light, so 20 kHz of sound was rendered as a
    15 km wavelength rather than the 17 mm it actually is in air. Bands are now
    placed by kind rather than by whether the arithmetic happens to yield a number,
    so mechanical and gravitational channels are excluded by construction.
    The opposite error was also present: Magnetic and ELF/VLF is electromagnetic
    and belon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
2026-07-28 Fix what a 63-agent adversarial audit found: 3 critical, 25 high
    Seven independent reviewers examined security, data integrity, firmware,
    factual accuracy, accessibility, web robustness, and cross-cutting consistency.
    Every finding was then attacked by a separate skeptic instructed to refute it.
    55 findings, 44 survived, 11 were correctly refuted.
    The worst one was found twice, independently, which is the strongest signal
    available. Agent.__init__ constructed its Clock with GNSS_PPS and a fabricated
    240 ns offset on every non-simulated run, and update_from_chrony was called
    only from tests. So the clock gate -- the single strongest brake on the
    classification ladder, the one with its own fi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
    [agent.py, config.py]
2026-07-28 Replay protection, coincidence correctness, and the rest of the audit
    Ingest requests are now single-use. Signatures cover the path, a timestamp and
    a nonce as well as the body, the grid records every accepted nonce, and a
    replay collides on the primary key. Verified against the live deployment: a
    resent request returns 409, a 15-minute-old timestamp returns 401, and a
    signature minted for /heartbeat presented at /telemetry returns 401. Enrolment
    mattered most here, because the secret is only demanded for a new slug, so a
    captured enrolment could previously be resent with no secret at all to reset a
    live node to 'provisioning' and wipe its channel list.
    The coincidence detector had three fa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
    [agent.py, core.py, sensors.py]
2026-07-28 Move to Xaxis/nband and make the repository navigable
    The repository was still called bifrost while the project, the domain, the
    schema, the packages and 22 documentation links all said nband. The full
    history moved to github.com/Xaxis/nband; the old repository is archived with a
    pointer rather than deleted, because its URL may already be somewhere. The
    local checkout moved too, with a symlink for anything holding the old path.
    Organisation. There is now one entry point: `make`, with `make check` running
    exactly what CI runs, so what a contributor verifies locally and what the
    workflow verifies cannot diverge. Added the conventions that were missing
    entirely: CONTRIBUTING, SECURITY with the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
    [agent.py, sensors.py]
2026-07-28 Read channels on their own threads, and close the last audit items
    Every driver read happened inline on the single main loop, so any channel that
    blocked blocked all of them. That is not hypothetical: an SDR read is tens of
    milliseconds, a camera capture can be hundreds, and a serial read sits on its
    full timeout when the sensor is unplugged. One dead UART would have produced
    gaps across a node's optical channels that look exactly like quiet sky rather
    than a wiring fault.
    Each channel now runs a worker thread that owns its driver and its cadence and
    posts samples to a bounded queue. Triggering, the noise floors and spooling stay
    on the one consuming thread, so none of that needs locking: e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
    [agent.py]
2026-07-28 Pin the toolchain, and stop two stub configs shadowing the shared one
    CI failed while `make check` passed locally, which is precisely the divergence
    the Makefile was introduced to prevent. Two separate causes, both worth stating.
    The toolchain was unpinned. CI ran `pip install ruff` and got whatever resolved
    that day; the author had an older one. Same commands, different tools,
    different answers. requirements-dev.txt now pins ruff and cryptography, CI
    installs from it, and `make install` uses the same file.
    `make lint` also skipped the Python lint entirely with a friendly message when
    ruff was absent, which means the one configuration guaranteed to pass locally
    was the one guaranteed to fa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
    [agent.py, core.py, sensors.py]
2026-07-28 Fix a privacy guarantee that was false, and a correction that was wrong
    A public-readiness audit found two things that were publicly untrue, and
    one of them was in the passage this project points at when it talks about
    intellectual honesty.
    Published node positions could be de-fuzzed to about five metres. The
    offset's bearing came from an FNV hash of the node's Ed25519 public key,
    and that key sat in a world-readable column, so anyone could recompute the
    offset and subtract it. The radius was always exactly location_precision_m,
    so every node sat on a known circle rather than anywhere inside a disc: at
    the default 1 km precision that is a 0.14 km annulus instead of 3.1 km of
    area. Four page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
    [sensors.py]
2026-07-28 Give tier 3 enough USB power to run the devices it sells you
    Tier 3 lists five bus-powered peripherals drawing 12.3 W between them,
    which is 2.46 A at 5 V, against a Raspberry Pi 5 that budgets 1.6 A across
    all its USB ports even with a 5 A supply, and has four ports for five
    devices. Nobody had added it up.
    The failure mode is the bad kind. A host that refused to enumerate the
    fifth device would at least be honest; instead the Pi brown-outs
    peripherals under load, so channels drop out intermittently under exactly
    the conditions that produce something worth recording, and it reads as
    flaky hardware rather than as a power budget that was never checked.
    Adds a powered hub to the tier 3 bill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
2026-07-28 State the americium unit error precisely: one dropped exponent, not two compounding slips
    The corrected passage described the mistake as two errors compounding to a
    thousandfold overstatement, partially cancelling. That is not what happened
    and it is a careless thing to write in the one paragraph on this site whose
    subject is being careless with a number.
    Converting milligray to microgray multiplies by a thousand and converting
    gigabecquerels to megabecquerels divides by a thousand. They cancel exactly,
    so 3.2e-2 mGy.m2/(GBq.h) is 3.2e-2 uSv.m2/(MBq.h) and the published 3.2 was
    the mantissa with the exponent left behind. A factor of exactly one hundred,
    from one keystroke.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
2026-07-28 Compile the wiring table into a circuit, so a bad pin fails the build
    schema/hardware.json records which physical header pin every sensor signal
    lands on. Until now that table was only ever rendered as prose and a
    diagram, and prose does not fail to compile. It said the LD2450's UART went
    to physical pins 16 and 18, which have no UART alternate function, while
    assigning that same pin 16 to the infrared beacon's gate as well. Both
    errors sat in a published wiring guide until someone read it closely.
    tools/gen-boards.mjs now emits one tscircuit board per tier from that same
    table: the Pi 40-pin header, a connector per header-connected module, and a
    trace per signal. 4 modules and 17 signals o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
2026-07-28 Run the carrier board check in CI
    The cheap half needs no toolchain: it regenerates the board sources from
    schema/hardware.json and fails if the checked-in ones differ, and it
    verifies the rendered artifacts on the site describe the same boards. That
    catches the ordinary mistake of editing the registry and running
    `make codegen` without `make boards`.
2026-07-28 Label the header by Pi pin number, and put all three views on the page
    The header numbering was wrong, and wrong in the way that only shows up
    after a board is fabricated.
    A tscircuit doubleRow pinheader numbers its pins the way an IC package
    does, counter-clockwise: the top row reads 1, 40, 39 ... 22 and the bottom
    row 2, 3, 4 ... 21. The Raspberry Pi numbers odd pins along one row and
    even along the other. Only pins 1 and 2 agree. Physical pin 7 -- the GNSS
    pulse-per-second input, the one connection the whole clock discipline
    rests on -- is index 38 in the connector's own scheme, so the generator
    emitting `.J1 > .pin7` had quietly wired PPS to physical pin 12, the I2S
    bit clock. Nothing i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
2026-07-28 Make the 3D panel's ready state independent of the camera maths
    Clearing the loading overlay was the last statement in the GLTF onLoad
    callback, after the bounding-box fit. Anything that threw in between left
    "Loading model..." sitting on top of a model that had loaded perfectly
    well, and because GLTFLoader routes a throwing onLoad to onError, the
    failure would have been attributed to the wrong cause. Ready now means the
    model is in the scene, which is what the word should mean; framing happens
    after.
    Two things that could have thrown, both now handled. The aspect ratio is
    clamped, because a host that has not been laid out reports a height of zero
    and an aspect of Infinity, which propagates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
2026-07-28 Make the carrier a real board, and stop the hardware page being one scroll
    Two complaints, both fair.
    The board was a connector fan-out, not a design. It had no decoupling, no
    pull-ups, no mounting holes, no ground plane, and a third of tier 3 would
    not route. Each board now carries a 100 nF capacitor per module placed at
    its connector, a bulk reservoir per supply rail, one pair of 4.7 k I2C
    pull-ups, a poured ground plane on the bottom layer, and the four HAT
    mounting holes at the positions the mechanical standard fixes. Tier 1 goes
    from 5 components to 12, tier 3 from 9 to 21.
    The pull-ups need a word. Every breakout carries its own, which is the
    problem: three in parallel load the bus t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
2026-07-28 Fix what an adversarial audit found: broken links, a touch trap, checks that never ran
    An audit across six dimensions returned findings in every one. These are the
    confirmed ones I could verify directly.
    The routing pass and the header-numbering tripwire were in no aggregate
    target. `boards-verify` only ever ran when someone typed it, while the page
    said the boards were checked on every build. That tripwire is the one built
    specifically to catch the Pi-versus-connector pin numbering bug, so it was
    the check that mattered most and the one running least. It is now part of
    `make check`. CI still runs the cheap half because it has no board
    toolchain, and says so rather than passing silently.
    P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
2026-07-28 Add the parts the boards could not work without, and measure copper clearance
    An adversarial audit returned 97 findings, 24 verified. Three of the confirmed
    ones were the same defect in different places: the registry declared things
    that could not physically exist.
    The SM-24 geophone was listed with six SPI pins and a driver named
    geophone_ads1256, and the ADS1256 was in no bill of materials. An SM-24 is a
    coil moving in a magnetic field: two wires, tens of millivolts, no supply, no
    clock, no chip select. The generated wiring reference showed a geophone
    connected directly to the Pi's SPI bus, which is not a thing that can work,
    published as "the wiring reference". The ADC is now a part carr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
2026-07-28 Remove the I2C pull-ups, which caused the loading they were added to fix
    The carrier fitted a 4.7 k pull-up pair with a comment explaining that the
    breakouts' own resistors in parallel overload the bus. The reasoning was
    right and the conclusion was backwards.
    The Raspberry Pi fits 1.8 k to 3V3 on GPIO2 and GPIO3, on the board, not
    removable. A tier 3 bus with four breakouts at 10 k each already sits at
    1,047 ohms and works. Adding 4.7 k on top takes it to 856, and I2C needs at
    least (3.3 - 0.4) / 3 mA, about 967 ohms, to pull a valid low. The pair
    added to fix over-loading was the thing that pushed the bus out of
    specification.
    The failure this would have produced is the bad kind. Not a d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
2026-07-28 Record logic voltage, and stop the emitter gate floating at power-on
    Two parts run from a 5 V rail and also land signal pins on the GPIO header.
    Both are fine, because their logic is 3.3 V even though their supply is not,
    but that was true by luck rather than by check: the registry had no field
    distinguishing supply voltage from logic voltage, so nothing could tell the
    safe case from the damaging one. The Pi's GPIO is not 5 V tolerant, and a
    future part on a 5 V rail with 5 V logic would have been drawn straight onto
    the header with no warning anywhere.
    electrical.logicVoltage now exists on every part that lands a GPIO pin, and a
    drift check refuses anything above 3.3 V or missing the field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
2026-07-28 Put each part where it physically goes, not where a connector was convenient
    The assembly drew the magnetometer bolted to the carrier while the same
    part's registry note, rendered a few hundred pixels away on the same page,
    asks for at least two metres of separation from the node's electronics on a
    non-ferrous mast section. A render that contradicts the text beside it is
    worse than no render.
    Working through the rest of the list, most of them were wrong for the same
    reason: placement had been decided by which connector was free rather than by
    what the sensor has to be near. A BME688 bolted above the Raspberry Pi
    measures the Pi's temperature, not the site's. The UV and thermal sensors
    need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
2026-07-28 Check the node fits the case, and undo the fix I made from a bad measurement
    The enclosure was drawn from its exterior dimensions and nothing checked that
    the contents fit, which is the only question those numbers are for. Pelican
    publishes both; only the interior was missing.
    The first version of the check measured the bounding box of the assembly and
    reported tier 3 filling 97 percent of the case. That looked damning, so I
    specified a larger case for tier 3, moved the budget to accommodate it, and
    wrote a note explaining why the smaller one does not close.
    It was measuring the wrong thing. The assembly is a display arrangement: it
    spreads the USB peripherals across the bench so they can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
2026-07-28 Protect the lines that leave the box, and let the build size the board itself
    The carrier had no protection of any kind, and the exposure is not
    theoretical. Two signals leave the enclosure on multi-metre cables: the
    magnetometer sits two metres out on a non-ferrous mast section because its
    own datasheet asks for that, and the geophone is ground-coupled and further
    still. Both are on a shared SPI bus. A cable that long on a mast is an
    antenna, and a nearby strike does not have to be close to induce a transient
    that walks back into the Pi through whichever device is listening.
    So every line that leaves the box now has a TVS clamp, and each supply rail
    has a resettable fuse and a reverse-pola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
2026-07-28 The GNSS receiver was missing from every assembly and nothing noticed
    The part the entire clock discipline rests on — the receiver whose
    pulse-per-second output is the difference between a node that can join an
    array and one that can only file solo reports — was absent from all three
    node models.
    Its mechanical.mount is 'hat', the hat slot was assumed to mean the generated
    carrier, and a part whose mount matched nothing was dropped without a word.
    The model showed a tier 1 node with eight parts in its bill of materials and
    seven bodies, and read as though tier 1 simply did not include a GNSS.
    A silent omission is the worst version of this. A crash gets fixed; a missing
    body reads as a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
2026-07-28 The header was 44 mm from where the HAT specification puts it
    The mounting hole pattern was right from the first version: 58 mm by 49 mm,
    exactly the four positions the HAT mechanical specification fixes. The header
    was not. It sat at y = -21 because that number looked about right, and the
    specification puts pin 1 level with the top row of holes, 4 mm inboard of the
    left column. Forty-four millimetres out, on the opposite edge of the board.
    A board fabricated that way bolts onto the standoffs and does not reach the
    Pi's pins. It is not a subtle failure, and it survived because the position
    was a literal and literals are not checked against anything.
    The header is now expressed relative to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
2026-07-28 Make the node rendering show a node
    It was a pile of anonymous coloured boxes on a grid. A Raspberry Pi drawn as
    one green slab the height of its Ethernet jack tells you nothing, peripherals
    floated beside boards they had no visible relationship to, and the boards in
    the stack hung above one another with nothing between them. Useless is the
    right word for it.
    Three things were missing, and all three are what makes the picture readable.
    Connectors. A Pi is recognisable almost entirely by its connector layout, so
    the board is drawn as a bare 1.6 mm board with its twelve features on top:
    the USB and Ethernet stacks, the two micro-HDMI and the USB-C, both CSI
    connectors, the GPIO header, the S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
2026-07-28 Rewrite the registry notes, which are rendered copy and read like a diary
    The part notes in schema/hardware.json are printed verbatim on the hardware
    page, and eight of them were autobiography. The Pelican entry explained that
    a larger case had briefly been specified on the strength of a measurement
    that turned out to be measuring the wrong thing. The USB hub described its
    own absence as a real defect in an earlier bill of materials. The current
    monitor recounted what the solar kits used to declare.
    A reader looking up a part wants to know what it is, why it is in the build,
    and what it cannot do. They are not owed a history of the file.
    So the notes say those things instead. The hub says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
2026-07-30 Make the printed enclosure printable, and find out what it weighs
    case-printed-asa had a price, an aperture list, a dimensioned drawing and the
    registry line "a design, not a product, and nobody has printed one". All true,
    and none of it printable: a plan view says where the windows go, not what to
    send to a printer. gen-enclosure-model.mjs builds the body and lid as solids and
    writes STL, placing the windows with lidLayout, which the drawing now calls as
    well rather than answering the same question in a second file.
    Making it solid contradicted the registry twice, in the two ways a drawing has
    no way to be wrong.
    The seal groove was 3.4 mm wide and the wall is 3 mm. On paper that is a das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
    [case-printed-asa-body.stl, case-printed-asa-lid.stl]
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
